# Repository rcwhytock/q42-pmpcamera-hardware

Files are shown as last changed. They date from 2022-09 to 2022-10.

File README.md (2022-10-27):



# Q42 PMP hardware

Q42 PMP is a standalone device featuring a Raspberry Pi and a Raspberry Pi Camera Module with a number of additonal features.

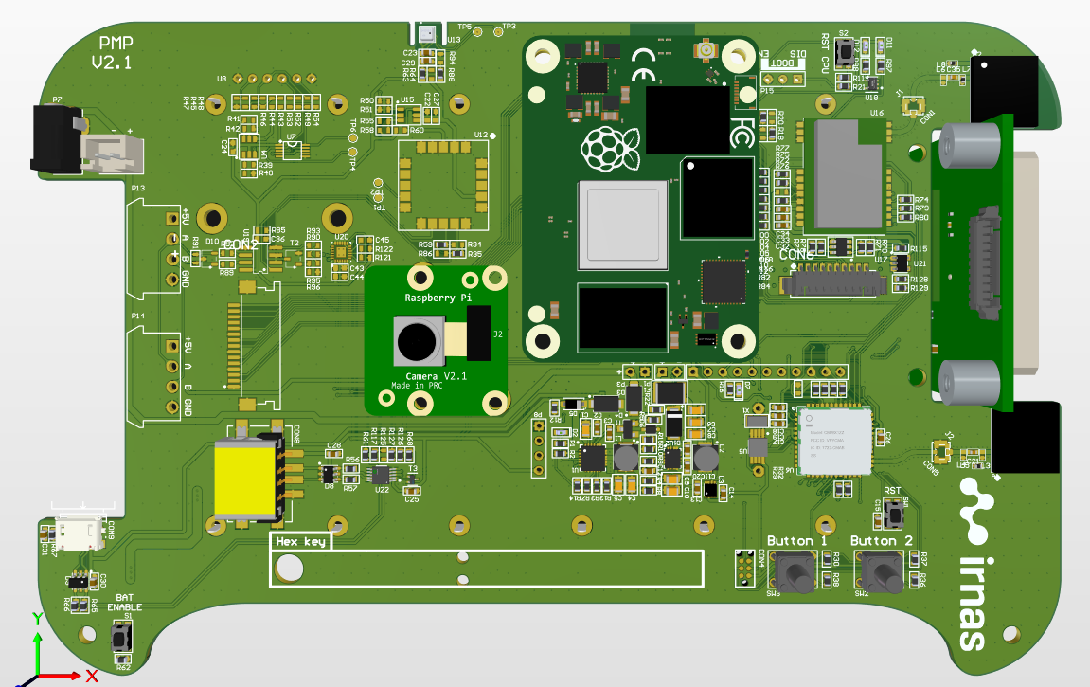
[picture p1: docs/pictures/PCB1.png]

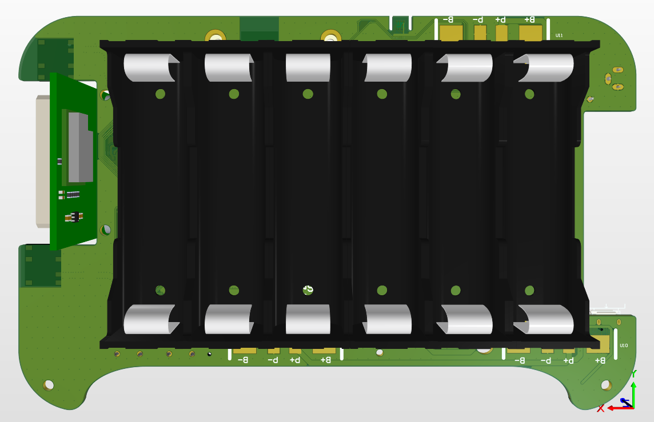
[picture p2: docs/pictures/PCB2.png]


## Key user features
* Capture image/video at defined intervals
* Report system status/sensors via Lora (optional)
* Report system status/sensors via RockBlock Iridium (optional)
* Optional sensors:
  * Ultrasonic distance
  * Temperatures
  * GPS - location
* Power:
  * Batteries
  * Solar charging
* USB flash drive - user removable - contains all images and other captured data
  * contains images/videos
  * contains json with settings
* SD card with OS is read-only and not to be removed
* on/off switch
* 2x push button
  * button 1: test mode - push to turn on the system for 10 minutes
  * button 2: general purpose
* Test mode:
  * WiFi enabled, user can connect and check camera image or download all images
  * Each time test mode is enabled an image is taken.
* Bluetooth:
  * System status printout
  * Enable test mode
  * Configure settings
* Lora:
  * Enable test mode 
  * Configure settings
  * LacunaSpace communication
 
## License

All our projects are as usefully open-source as possible.

Hardware including documentation is licensed under [CERN OHL v.1.2. license](http://www.ohwr.org/licenses/cern-ohl/v1.2)

Firmware and software originating from the project is licensed under [GNU GENERAL PUBLIC LICENSE v3](http://www.gnu.org/licenses/gpl-3.0.en.html).

Open data generated by our projects is licensed under [CC0](https://creativecommons.org/publicdomain/zero/1.0/legalcode).

All our websites and additional documentation are licensed under [Creative Commons Attribution-ShareAlike 4 .0 Unported License](https://creativecommons.org/licenses/by-sa/4.0/legalcode).

What this means is that you can use hardware, firmware, software and documentation without paying a royalty and knowing that you'll be able to use your version forever. You are also free to make changes but if you share these changes then you have to do so on the same conditions that you enjoy.

Koruza, GoodEnoughCNC and IRNAS are all names and marks of Institut IRNAS Race. 
You may use these names and terms only to attribute the appropriate entity as required by the Open Licences referred to above. You may not use them in any other way and in particular you may not use them to imply endorsement or authorization of any hardware that you design, make or sell.

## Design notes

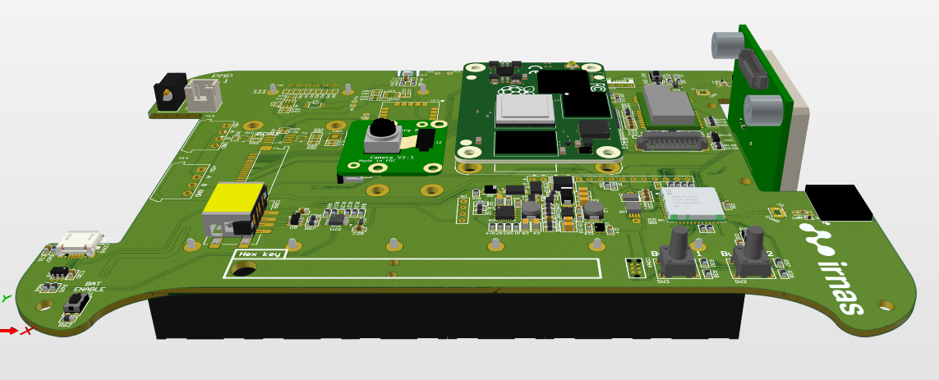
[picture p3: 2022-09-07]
docs/pictures/PCB3.png

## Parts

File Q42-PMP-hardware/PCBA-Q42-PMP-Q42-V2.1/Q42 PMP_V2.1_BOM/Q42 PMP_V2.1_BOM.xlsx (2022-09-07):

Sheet: Part List Report
 | Component list |  |  | Q42 PMP
 | Source Data From: | Q42-PMP.PrjPCB
 | Project: | Q42-PMP.PrjPCB
 | Variant: | Q42
 | Version: | V2.1
 | Report Date: | 7. 09. 2022 | 08:28
 | Print Date: | 2022-09-07 | 8:29:03
# | Manufacturer Part Number | Manufacturer | Description | Footprint | Designator | Value | Quantity | Supplier 1 | Supplier Part Number 1 | #Column Name Error:' IRNAS Internal | Total Quantity
1 |  |  | BATERRY HOLDER 18650 | BATTERY HOLDER 18650 | P5, P6, P9, P10, P11, P12 |  | 6 |  | Battery holder for 18650 |  | 120
2 |  |  | BATTERY PROTECTION | BATTERY PROTECTION | U9, U10, U11 |  | 3 |  | Battery protection |  | 60
3 |  |  | Humidity Temperature Sensor 0 ~ 100% RH I²C, SPI ±3% 1s Surface Mount | BME280 | U13 |  | 1 | Digi-Key | 828-1063-6-ND |  | 20
4 |  |  | Tactile Switch, B3F Series, Top Actuated, Through Hole, Round Button, 100 gf, 50mA at 24VDC | BTN B3F-1070 | SW2, SW3 |  | 2 | Farnell | 959698 |  | 40
5 |  |  | CAP CER 1.5PF 50V C0G/NP0 0402 | CAP0402 | C35 | 1.5pF | 1 | Digi-Key | 490-6212-1-ND |  | 20
6 |  |  | CAP CER 3.0PF 50V C0G/NP0 0402 | CAP0402 | C21 | 3.0pF | 1 | Digi-Key | 490-7756-1-ND |  | 20
7 | C0603C106M8PACTU | KEMET | 10uf/0603/20% | CAP0603 | C19 |  | 1 | Farnell | 2820985 |  | 20
8 | CL10A106KP8NNNC | Samsung | Cap Ceramic 10uF 10V X5R 10% SMD 0603 85C Paper T/R | CAP0603 | C32 |  | 1 | Digi-Key | 1276-1192-1-ND |  | 20
9 | MC0603B473K500CT | MULTICOMP | MULTICOMP - MC0603B473K500CT - CAP, MLCC, X7R, 47NF, 50V, 0603 | CAP0603 | C3 |  | 1 | Farnell | 1759116 |  | 20
10 | GRM188R61C106KAALD | Murata | Multilayer Ceramic Capacitors MLCC - SMD/SMT 0603 10uF 16volts X5R 10% | CAP0603 | C11, C20 |  | 2 | Farnell | 2611923 |  | 40
11 | GRM188R61C475KAAJD | MURATA | MURATA - GRM188R61C475KAAJD - CAP, MLCC, X5R, 4.7UF, 16V, 0603 | CAP0603 | C2 |  | 1 | Farnell | 2611924 |  | 20
12 | GRM188R61C475KAAJD | MURATA | MURATA - GRM188R61C475KAAJD - CAP, MLCC, X5R, 4.7UF, 16V, 0603 | CAP0603 | C13 |  | 1 | Farnell | 2611924 |  | 20
13 | GRM188R61H105KAALD | MURATA | MURATA - GRM188R61H105KAALD - CAP, MLCC, X5R, 1UF, 50V, 0603 | CAP0603 | C17 |  | 1 | Farnell | 1845736 |  | 20
14 | GRM188R61H105KAALD | MURATA | MURATA - GRM188R61H105KAALD - CAP, MLCC, X5R, 1UF, 50V, 0603 | CAP0603 | C26, C29, C33 |  | 3 | Farnell | 1845736 |  | 60
15 | GRM188R71C104KA01J | MURATA | MURATA - GRM188R71C104KA01J - CAP, MLCC, X7R, 0.1UF, 16V, 0603 | CAP0603 | C12, C15, C18, C25 |  | 4 | Farnell | 2688519 |  | 80
16 | GRM188R71C104KA01J | MURATA | MURATA - GRM188R71C104KA01J - CAP, MLCC, X7R, 0.1UF, 16V, 0603 | CAP0603 | C23, C28, C30, C31, C34 |  | 5 | Farnell | 2688519 |  | 100
17 |  |  | SMD Multilayer Ceramic Capacitor, 2.2 µF, 6.3 V, 0603 [1608 Metric], ± 10%, X5R, MC Series | CAP0603 | C14 |  | 1 | Farnell | 1759392 |  | 20
18 | MC0805X226M6R3CT | MULTICOMP | MULTICOMP - MC0805X226M6R3CT - CAP, MLCC, X5R, 22UF, 0805 | CAP0805 | C7, C8, C9, C10 |  | 4 | Farnell | 1759415 |  | 80
19 | CGA4J1X5R1C106K125AC | TDK | TDK - CGA4J1X5R1C106K125AC - CAP, MLCC, X5R, 10UF, 16V, 0805 | CAP0805 | C1, C4, C5, C6 |  | 4 | Farnell | 2320856 |  | 80
20 | MINISMDC150F/24-2 | LITTELFUSE | LITTELFUSE - MINISMDC150F/24-2 - POLYSWITCH, SMD, 1812, 1.5A | Chip2PinSM127P600-8N | F1 |  | 1 | Farnell | 1345929 |  | 20
21 | MM8130-2600 | Murata | Coaxial Connector with Switch | COAXIAL-SWF | J1, J2 | MM8130-2600 | 2 |  |  |  | 40
22 |  |  |  | E22-900M22S | U16 |  | 1 |  |  |  | 20
23 | FDSD0420-H-1R5M=P3 | MURATA | MURATA - FDSD0420-H-1R5M=P3 - INDUCTOR, SHIELDED, 1.5UH, 5.1A, 20% | FDSD0402 | L1, L2 |  | 2 | Farnell | 2530091 |  | 40
24 |  |  | Header, 3-Pin | HDR1X3 | P15 |  | 1 |  |  |  | 20
25 | LQG15WH18NJ02D | MURATA | 18 nH, 0.8 ohm, 2.3 GHz, 260 mA, 0402 | IND0402 | L7 | 18nH | 1 | Farnell | 3263541 |  | 20
26 |  |  | IND 12NH 500MA 280 MOHM | IND0402 | L3 | 12nH | 1 | Digi-Key | 490-2624-1-ND |  | 20
27 |  |  | Multilayer Inductor, 1 nH, 0.07 ohm, 10 GHz, 1 A, 0402 [1005 Metric], LQG15HS_02 Series | IND0402 | L8 |  | 1 | Farnell | 3471230 |  | 20
28 |  |  | Multilayer Inductor, AEC-Q200, 2.1 nH, 0.06 ohm, 8 GHz, 1 A, 0402 [1005 Metric], LQG15WH_02 Series | IND0402 | L5 |  | 1 | Farnell | 3263552 |  | 20
29 |  |  | Wire-To-Board Connector, Vertical, 2.5 mm, 2 Contacts, Header, XH Series, Through Hole, 1 Rows | JST_2PIN_TH | CON7 |  | 1 | Farnell | 1516276 |  | 20
30 | HSMS-C190 | BROADCOM LIMITED | BROADCOM LIMITED - HSMS-C190 - LED, RED, 10MCD, 626NM | LED0603 | D12 |  | 1 | Farnell | 2497356 |  | 20
31 | HSMS-C190 | BROADCOM LIMITED | BROADCOM LIMITED - HSMS-C190 - LED, RED, 10MCD, 626NM | LED0603 | D2 |  | 1 | Farnell | 2497356 |  | 20
32 | HSMS-C190 | BROADCOM LIMITED | HSME-C191 - LED, Green, SMD, 0603, 20 mA, 2.1 V, 572 nm | LED0603 | D7, D11 |  | 2 | Farnell | 1219743 |  | 40
33 | LFXTAL009678 | IQD | CRYSTAL, 32.768KHZ, 12.5PF, SMD | LFXTAL009678 | X1 |  | 1 | Farnell | 2449398 |  | 20
34 | CMWX1ZZABZ-091 | Murata | Lora Module Murata | Lora Module ES0 | U6 |  | 1 | Farnell | 2802546 |  | 20
35 | SR42I010-R | Antenova | Antenna SMD -4dBi Gain 870MHz/928MHz Automotive 7-Pin SMD T/R | LORA_PCB_ANTENNA | A2 |  | 1 | Mouser | 237-SR42I010-L |  | 20
36 |  |  |  | microUSB-CHINA | CON9 |  | 1 |  |  |  | 20
37 |  |  | Analogue Switch, UART, 2 Channels, DPDT, 4.5 ohm, 2.4V to 3.6V, MSOP, 10 Pins | MSOP-10 | U22 |  | 1 | Farnell | 2564479 |  | 20
38 |  |  | Wire-To-Board Connector, Right Angle, 1.25 mm, 10 Contacts, Header, PicoBlade 53261 Series | PICOBLADE 10PIN | CON6 |  | 1 | Farnell | 1125377 |  | 20
39 | BQ24296RGET | Texas Instruments | IC LI+ CHARGER PWR MGMT 24VQFN | QFN4x4 | U1 |  | 1 | Farnell | 2373541 |  | 20
40 |  |  | Raspberry Pi Compute Module 4 (! order 2 connectors !) | Raspberry pi CM4 | CM4 |  | 1 | Farnell | 3493346 |  | 20
41 | CR0603-J/-000ELF | BOURNS | BOURNS - CR0603-J/-000ELF - RES, THICK FILM, 0R, 5%, 0.1W, 0603 | RES0603 | R4, R22 |  | 2 | Farnell | 2008343 |  | 40
42 | CR0603-J/-000ELF | BOURNS | BOURNS - CR0603-J/-000ELF - RES, THICK FILM, 0R, 5%, 0.1W, 0603 | RES0603 | R18, R19, R21, R35, R59, R63, R69, R75, R76, R79, R80, R81, R84, R88, R115, R116, R117, R120 |  | 18 | Farnell | 2008343 |  | 360
43 | MC0063W060311M | MULTICOMP | MULTICOMP - MC0063W060311M - RES, THICK FILM, 1M, 1%, 0.063W, 0603 | RES0603 | R67 |  | 1 | Farnell | 9330410 |  | 20
44 | MC0063W06031100R | MULTICOMP | MULTICOMP - MC0063W06031100R - RES, THICK FILM, 100R, 1%, 0.063W, 0603 | RES0603 | R25, R28, R62, R70, R78, R100, R102, R103, R104, R105, R106, R107, R108, R109, R110, R111, R112, R128 |  | 18 | Farnell | 9330364 |  | 360
45 | MCMR06X102 JTL | MULTICOMP | MULTICOMP - MCMR06X102 JTL - RES, CERAMIC, 1K, 5%, 0.1W, 0603 | RES0603 | R16, R38, R97, R98 |  | 4 | Farnell | 2073354 |  | 80
46 | MCMR06X103 JTL | MULTICOMP | MULTICOMP - MCMR06X103 JTL - RES, CERAMIC, 10K, 5%, 0.1W, 0603 | RES0603 | R9, R10, R15 |  | 3 | Farnell | 2073356 |  | 60
47 | MCMR06X103 JTL | MULTICOMP | MULTICOMP - MCMR06X103 JTL - RES, CERAMIC, 10K, 5%, 0.1W, 0603 | RES0603 | R30, R37, R74, R77, R127, R129 |  | 6 | Farnell | 2073356 |  | 120
48 | MCMR06X104 JTL | MULTICOMP | MULTICOMP - MCMR06X104 JTL - RES, CERAMIC, 100K, 5%, 0.1W, 0603 | RES0603 | R32 |  | 1 | Farnell | 2073357 |  | 20
49 | MCMR06X104 JTL | MULTICOMP | MULTICOMP - MCMR06X104 JTL - RES, CERAMIC, 100K, 5%, 0.1W, 0603 | RES0603 | R71, R73 |  | 2 | Farnell | 2073357 |  | 40
50 | MCMR06X471 JTL | MULTICOMP | MULTICOMP - MCMR06X471 JTL - RES, CERAMIC, 470R, 5%, 0.1W, 0603 | RES0603 | R1, R14 |  | 2 | Farnell | 2073513 |  | 40
51 | MCMR06X2201FTL | MULTICOMP | MULTICOMP - MCMR06X2201FTL - RES, CERAMIC, 2K2, 1%, 0.1W, 0603 | RES0603 | R36 |  | 1 | Farnell | 2073429 |  | 20
52 | MCMR06X4701FTL | MULTICOMP | MULTICOMP - MCMR06X4701FTL - RES, CERAMIC, 4K7, 1%, 0.1W, 0603 | RES0603 | R6, R11 |  | 2 | Farnell | 2073509 |  | 40
53 | MCMR06X4702FTL | MULTICOMP | MULTICOMP - MCMR06X4702FTL - RES, CERAMIC, 47K, 1%, 0.1W, 0603 | RES0603 | R61, R68 |  | 2 | Farnell | 2073510 |  | 40
54 | MCMR06X5601FTL | MULTICOMP | MULTICOMP - MCMR06X5601FTL - RES, CERAMIC, 5K6, 1%, 0.1W, 0603 | RES0603 | R3 |  | 1 | Farnell | 2073537 |  | 20
55 | MCWR06X1503FTL | MULTICOMP | MULTICOMP - MCWR06X1503FTL - RES, THICK FILM, 150KOHM, 1%, 0.1W | RES0603 | R8 |  | 1 | Farnell | 2447254 |  | 20
56 | MCWR06X2200FTL | MULTICOMP | MULTICOMP - MCWR06X2200FTL - RES, THICK FILM, 220R, 1%, 0.1W, 0603 | RES0603 | R7 |  | 1 | Farnell | 2447298 |  | 20
57 | MCWR06X2200FTL | MULTICOMP | MULTICOMP - MCWR06X2200FTL - RES, THICK FILM, 220R, 1%, 0.1W, 0603 | RES0603 | R114 |  | 1 | Farnell | 2447298 |  | 20
58 | MCWR06X3302FTL | MULTICOMP | MULTICOMP - MCWR06X3302FTL - RES, THICK FILM, 33K, 1%, 0.1W, 0603 | RES0603 | R13 |  | 1 | Farnell | 2447342 |  | 20
59 | MCWR06X3901FTL | MULTICOMP | MULTICOMP - MCWR06X3901FTL - RES, THICK FILM, 3K9, 1%, 0.1W, 0603 | RES0603 | R5 |  | 1 | Farnell | 2447363 |  | 20
60 |  |  | SMD Chip Resistor, 5.1 kohm, ± 1%, 100 mW, 0603 [1608 Metric], Thick Film, General Purpose | RES0603 | R126 |  | 1 | Farnell | 1469819 |  | 20
61 |  |  | Thermistor, NTC, 10 kohm, B57321V2 Series, 4000 K, SMD, 0603 [1608 Metric] | RES0603 | R2 |  | 1 | Farnell | 1299914 |  | 20
62 | CRCW0603226KFKEA | Vishay | Thick Film Resistors - SMD 1/10watt 226Kohms 1% | RES0603 | R29 |  | 1 | Farnell | 2138531 |  | 20
63 | RCA060310R0FKEA | VISHAY | VISHAY - RCA060310R0FKEA - RES, AUTO, THICK FILM, 10R, 1%, 0603 | RES0603 | R12 |  | 1 | Farnell | 2616585 |  | 20
64 | RCA060310R0FKEA | VISHAY | VISHAY - RCA060310R0FKEA - RES, AUTO, THICK FILM, 10R, 1%, 0603 | RES0603 | R56, R57, R65, R66 |  | 4 | Farnell | 2616585 |  | 80
65 | RS1J-E3/61T.. | VISHAY | VISHAY - RS1J-E3/61T.. - DIODE, FAST, 1A, 600V, SMD | SMC/DO-214AC | D1 |  | 1 | Farnell | 9550143 |  | 20
66 | BZT52C6V2 | DIODES INC. | DIODES INC. - BZT52C6V2 - DIODE, ZENER, 6.2V, 0.5W, SOD-123 | SOD123 | D5 |  | 1 | Farnell | 1902438 |  | 20
67 | MM3Z3V0T1G | ON SEMICONDUCTOR | ON SEMICONDUCTOR - MM3Z3V0T1G - ZENER DIODE, 200MW, 3V, SOD-323 | SOD-323 2L | D6 |  | 1 | Farnell | 2463510 |  | 20
68 | SE30AFG-M3/6A | VISHAY | VISHAY - SE30AFG-M3/6A - RECTIFIER, ESD, 400V, 3A, DO-221AC | SODFL127P600-8N | D3, D4 |  | 2 | Farnell | 2313878 |  | 40
69 |  |  | ESD Protection Device, 17 V, SOT-23, 6 Pins, 6 V, 85 W, USBLC Series | SOT23-6 | D8, D9 |  | 2 | Farnell | 1269406 |  | 40
70 | MMBT3904 | ON SEMICONDUCTOR/FAIRCHILD | ON SEMICONDUCTOR/FAIRCHILD - MMBT3904 - TRANSISTOR, NPN, SOT-23 | SOT23127P600-8N | T1 |  | 1 | Farnell | 9846727 |  | 20
71 |  |  | 1.0 A Load Switch IC | SOT-25 | U21 | TCK106AF | 1 | Digi-Key | TCK106AFLFCT-ND |  | 20
72 |  |  | Buffer, 74LVC1G07, 1.65 V to 5.5 V, SOT-353-5 | SOT-353 | U18 |  | 1 | Farnell | 1845213 |  | 20
73 |  |  | Power MOSFET, N Channel, 20 V, 630 mA, 0.3 ohm, SOT-523, Surface Mount | SOT-523 | T3 |  | 1 | Farnell | 2543524 |  | 20
74 | SR42I010-R | Antenova | Antenna SMD -4dBi Gain 870MHz/928MHz Automotive 7-Pin SMD T/R | SR42I010-L | A1 |  | 1 | Mouser | 237-SR42I010-R |  | 20
75 | KMR221NGLFS | ITT C&K | SWITCH TACTILE SPST-NO 0.05A 32V | SW | S1, S2 |  | 2 | Farnell | 2845727 |  | 40
76 | KMR221NGLFS | ITT C&K | SWITCH TACTILE SPST-NO 0.05A 32V | Tactile button | SW1 |  | 1 | C&K Components | 2845727 |  | 20
77 |  |  | TEST POINT ROUND SMD | TestPoint:1.2x1.2mm | TP1, TP2, TP3, TP4, TP5, TP6 |  | 6 |  |  |  | 120
78 | ISL1208IU8Z-T7A | Intersil | IC RTC/CALENDAR I2C LP 8MSOP | TSOP65P500X110-8N | U5 |  | 1 | Farnell | 2543322 |  | 20
79 |  |  | Dual MOSFET, N and P Channel, 3.4 A, 30 V, 0.038 ohm, 10 V, 1 V | TSOT26 | U17 |  | 1 | Farnell | 2061522 |  | 20
80 |  |  | LDO Voltage Regulator, Fixed, 2.5 V to 5.5 V in, 3.3 V/150 mA out, 380 mV drop, VDFN-8 | VDFN_2x2 | U3 |  | 1 | Farnell | 2678434 |  | 20
81 | TPS630701RNMT | TEXAS INSTRUMENTS | TEXAS INSTRUMENTS - TPS630701RNMT - DC/DC CONV, BUCK-BOOST, 2.4MHZ, VQFN-15 | VQFN TPS | U2 |  | 1 | Farnell | 2643432 |  | 20
82 |  |  | USB Connector, USB Type A, USB 2.0, Receptacle, 4 Ways, Surface Mount, Horizontal | WE-629104190121 | CON8 |  | 1 | Farnell | 2749036 |  | 20
 |  |  |  |  |  | 0 | 169
Approved |  |  |  | Notes
 |  |  |  | pcs: |  |  | 20 |  | Total |  | #REF!
 |  |  |  |  |  |  |  |  | Price for 1pcs |  | #REF!

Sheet: Project Information
Project Full Path | C:\Users\HP\AppData\Local\TempReleases\Snapshot\1\Q42-PMP.PrjPCB
Project Filename | Q42-PMP.PrjPCB
Variant Name | Q42
Data-Source Filename | Q42-PMP.PrjPCB
Data-Source Full Path | C:\Users\HP\AppData\Local\TempReleases\Snapshot\1\Q42-PMP.PrjPCB
Title | BOM for Variant [Q42] of Project [Q42-PMP.PrjPCB] (No PCB Document Selected)
Total Quantity | 169
Report Time | 08:28
Report Date | 7. 09. 2022
Report Date & Tine | 7. 09. 2022 08:28
Output Name | BOM
Output Type | BomReport
Output Generator Name | BOM
Output Generator Description | Bill of Materials

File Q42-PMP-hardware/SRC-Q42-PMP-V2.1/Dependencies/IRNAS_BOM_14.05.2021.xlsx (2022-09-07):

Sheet: Part List Report
 | Component list |  |  | Field=ProjectTitle
 | Source Data From: | Field=DataSourceFileName
 | Project: | Field=ProjectFileName
 | Variant: | Field=VariantName
 | Version: | Field=Version
 | Report Date: | Field=ReportDate | Field=ReportTime
 | Print Date: | 2021-07-15 | 9:00:45
# | Column=Manufacturer Part Number | Column=Manufacturer | Column=Description | Column=Footprint | Column=Designator | Column=Value | Column=Quantity | Column=Supplier 1 | Column=Supplier Part Number 1 | Column=IRNAS Internal | Total Quantity
1 |  |  |  |  |  |  |  |  |  |  | #VALUE!
2 |  |  |  |  |  |  |  |  |  |  | #VALUE!
3 |  |  |  |  |  |  |  |  |  |  | #VALUE!
 |  |  |  |  |  | 0 | 0
Approved |  |  |  | Notes
 |  |  |  | pcs: |  |  | Field=ProductionQuantity |  | Total |  | #REF!
 |  |  |  |  |  |  |  |  | Price for 1pcs |  | #REF!

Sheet: Project Information
Project Full Path | Field=ProjectFullPath
Project Filename | Field=ProjectFileName
Variant Name | Field=VariantName
Data-Source Filename | Field=DataSourceFileName
Data-Source Full Path | Field=DataSourceFullPath
Title | Field=Title
Total Quantity | Field=TotalQuantity
Report Time | Field=ReportTime
Report Date | Field=ReportDate
Report Date & Tine | Field=ReportDateTime
Output Name | Field=OutputName
Output Type | Field=OutputType
Output Generator Name | Field=GeneratorName
Output Generator Description | Field=GeneratorDescription

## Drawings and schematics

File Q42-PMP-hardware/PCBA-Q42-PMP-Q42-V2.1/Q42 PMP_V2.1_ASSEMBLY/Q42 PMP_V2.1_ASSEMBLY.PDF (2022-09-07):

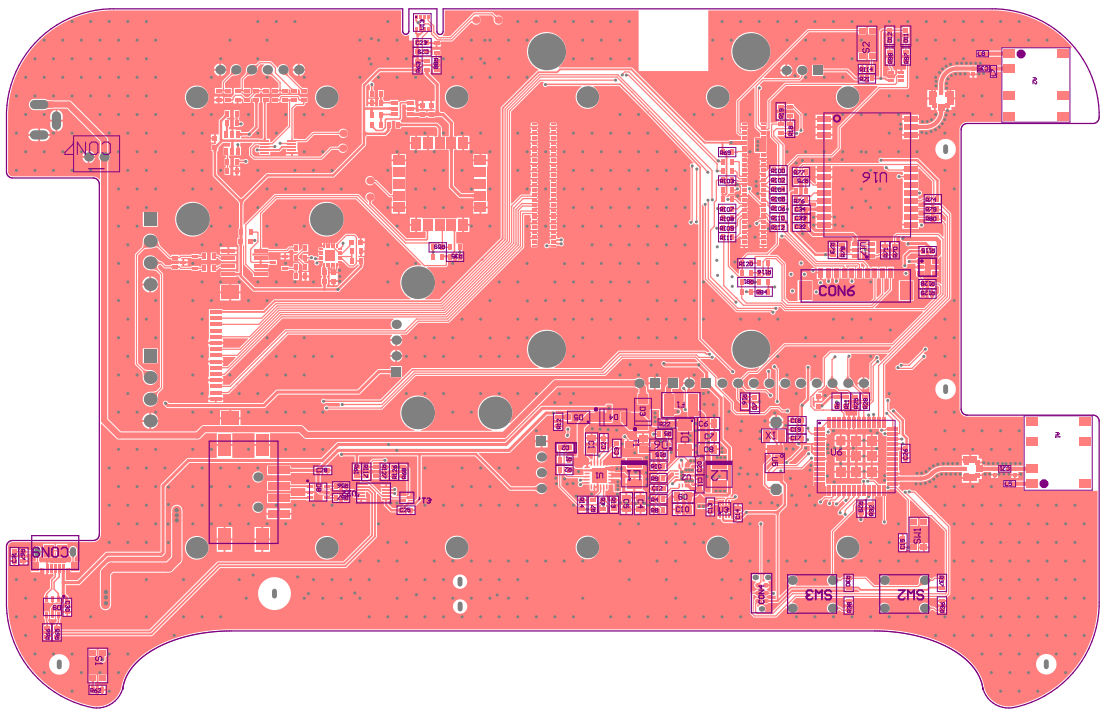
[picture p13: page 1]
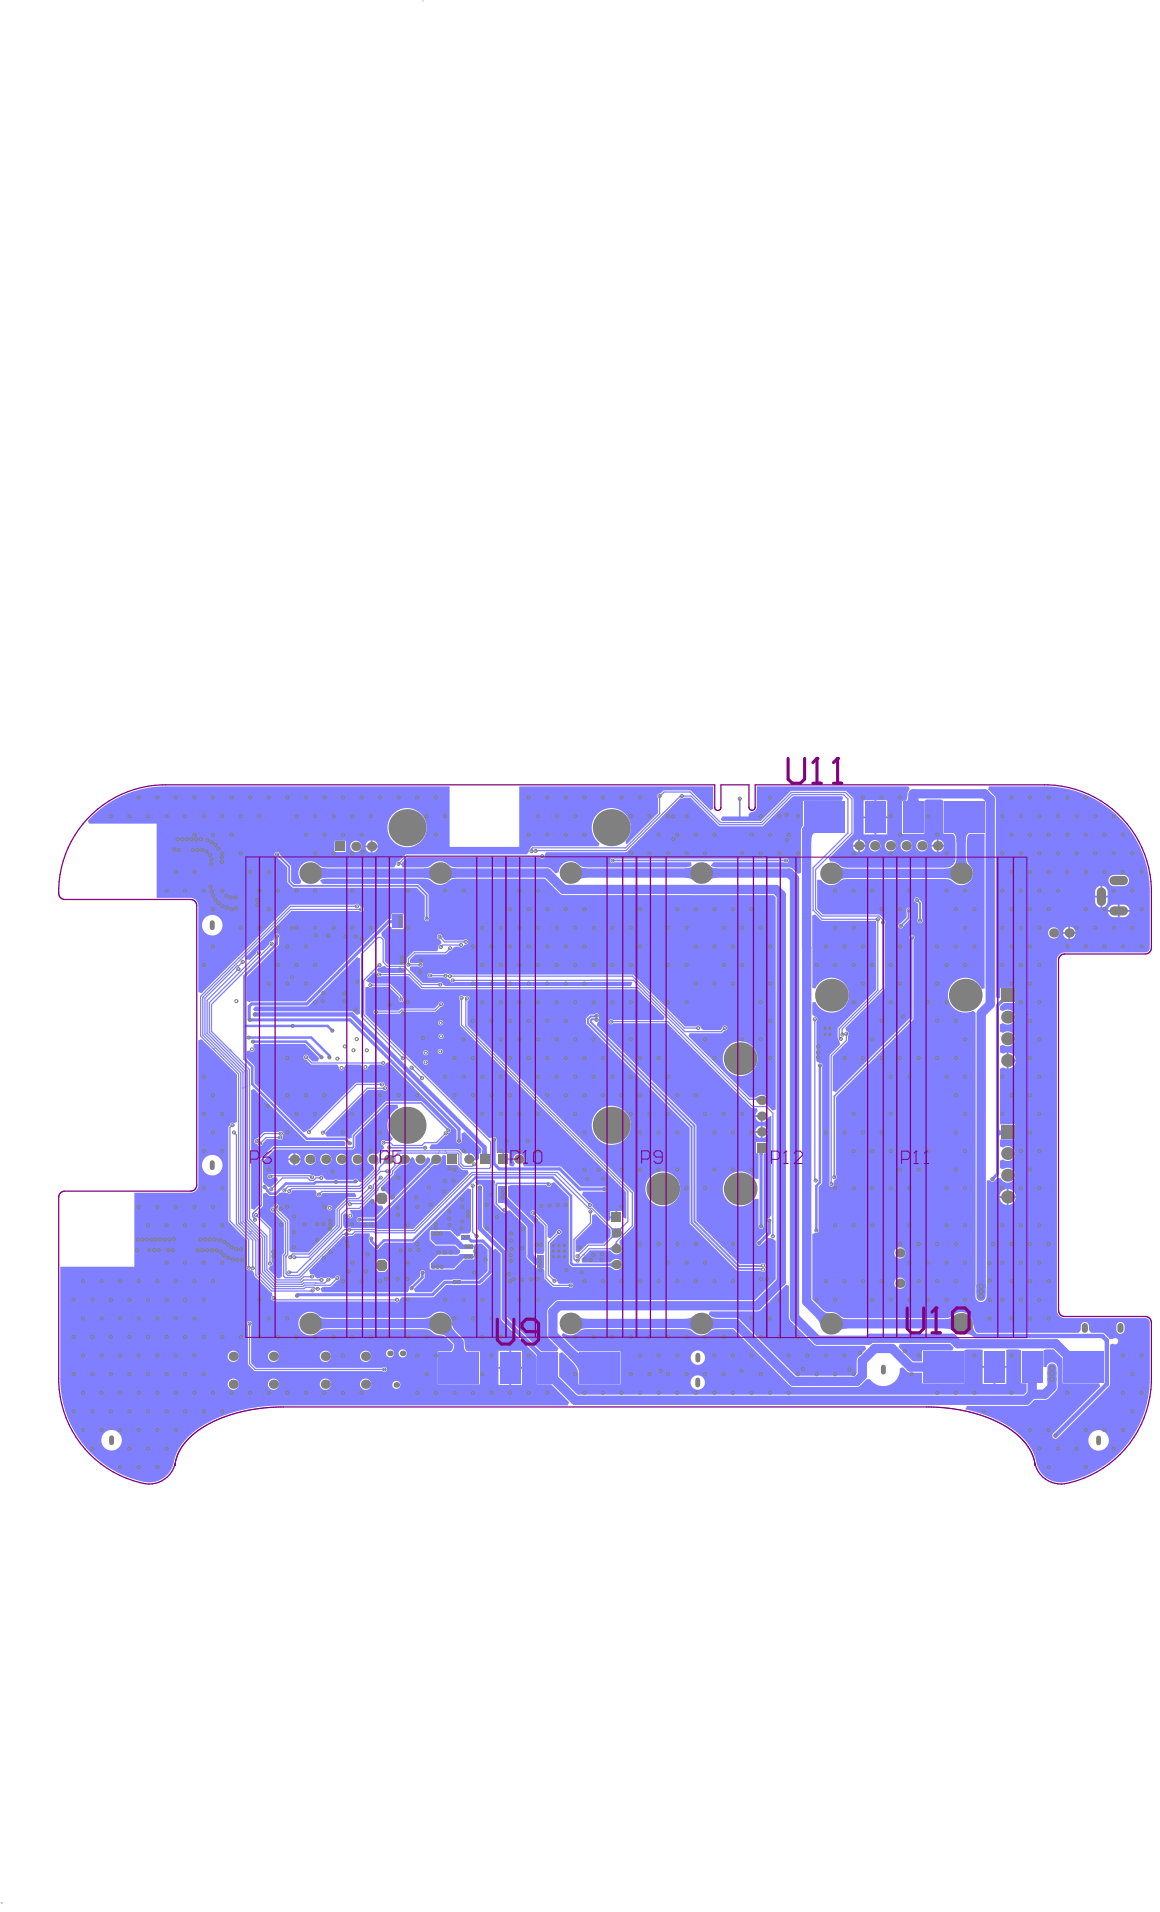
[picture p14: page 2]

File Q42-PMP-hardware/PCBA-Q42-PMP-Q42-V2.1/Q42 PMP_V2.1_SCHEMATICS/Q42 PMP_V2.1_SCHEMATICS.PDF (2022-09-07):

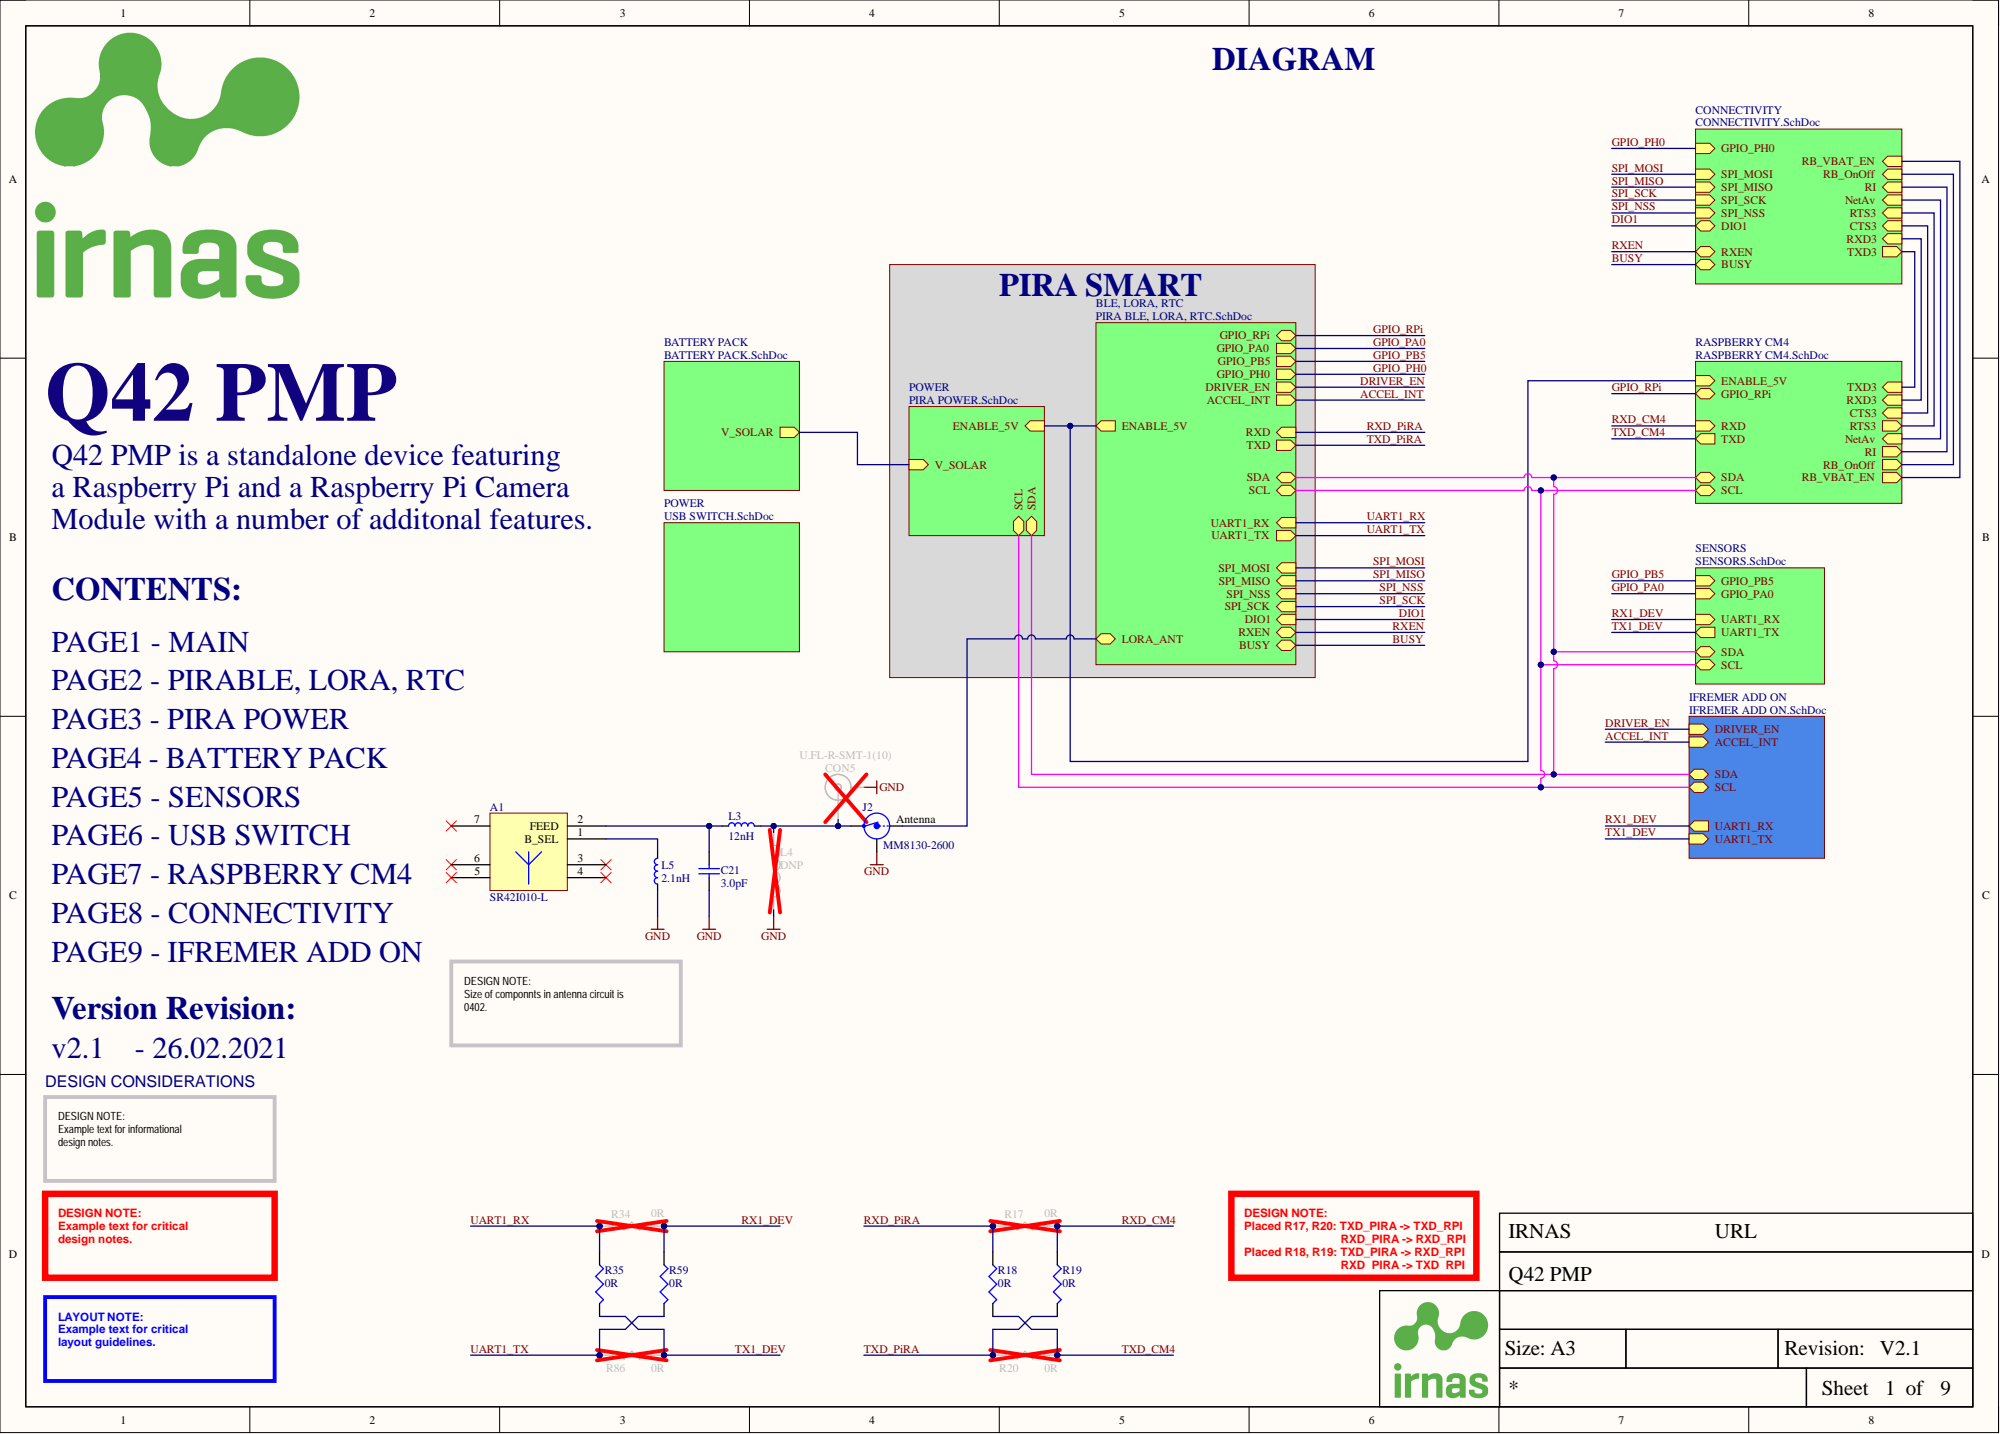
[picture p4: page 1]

BLE, LORA, RTC
PIRA BLE, LORA, RTC.SchDoc

DRIVER_EN ACCEL_INT ENABLE_5V RXD TXD SDA SCL UART1_RX | GPIO_RPi ACCEL_INT RXD_CM4 RXD_PiRA TXD_CM4 TXD_PiRA

Q42 PMP is a standalone device featuring
a Raspberry Pi and a Raspberry Pi Camera
Module with a number of additonal features.

UART1_TX SPI_MOSI SPI_MISO SPI_NSS SPI_SCK DIO1 RXEN LORA_ANT BUSY

DESIGN NOTE:
Size of componnts in antenna circuit is

Example text for informational
design notes.

Example text for critical

LAYOUT NOTE:
layout guidelines.

Size: A3 | | Revision: V2.1

Sheet of

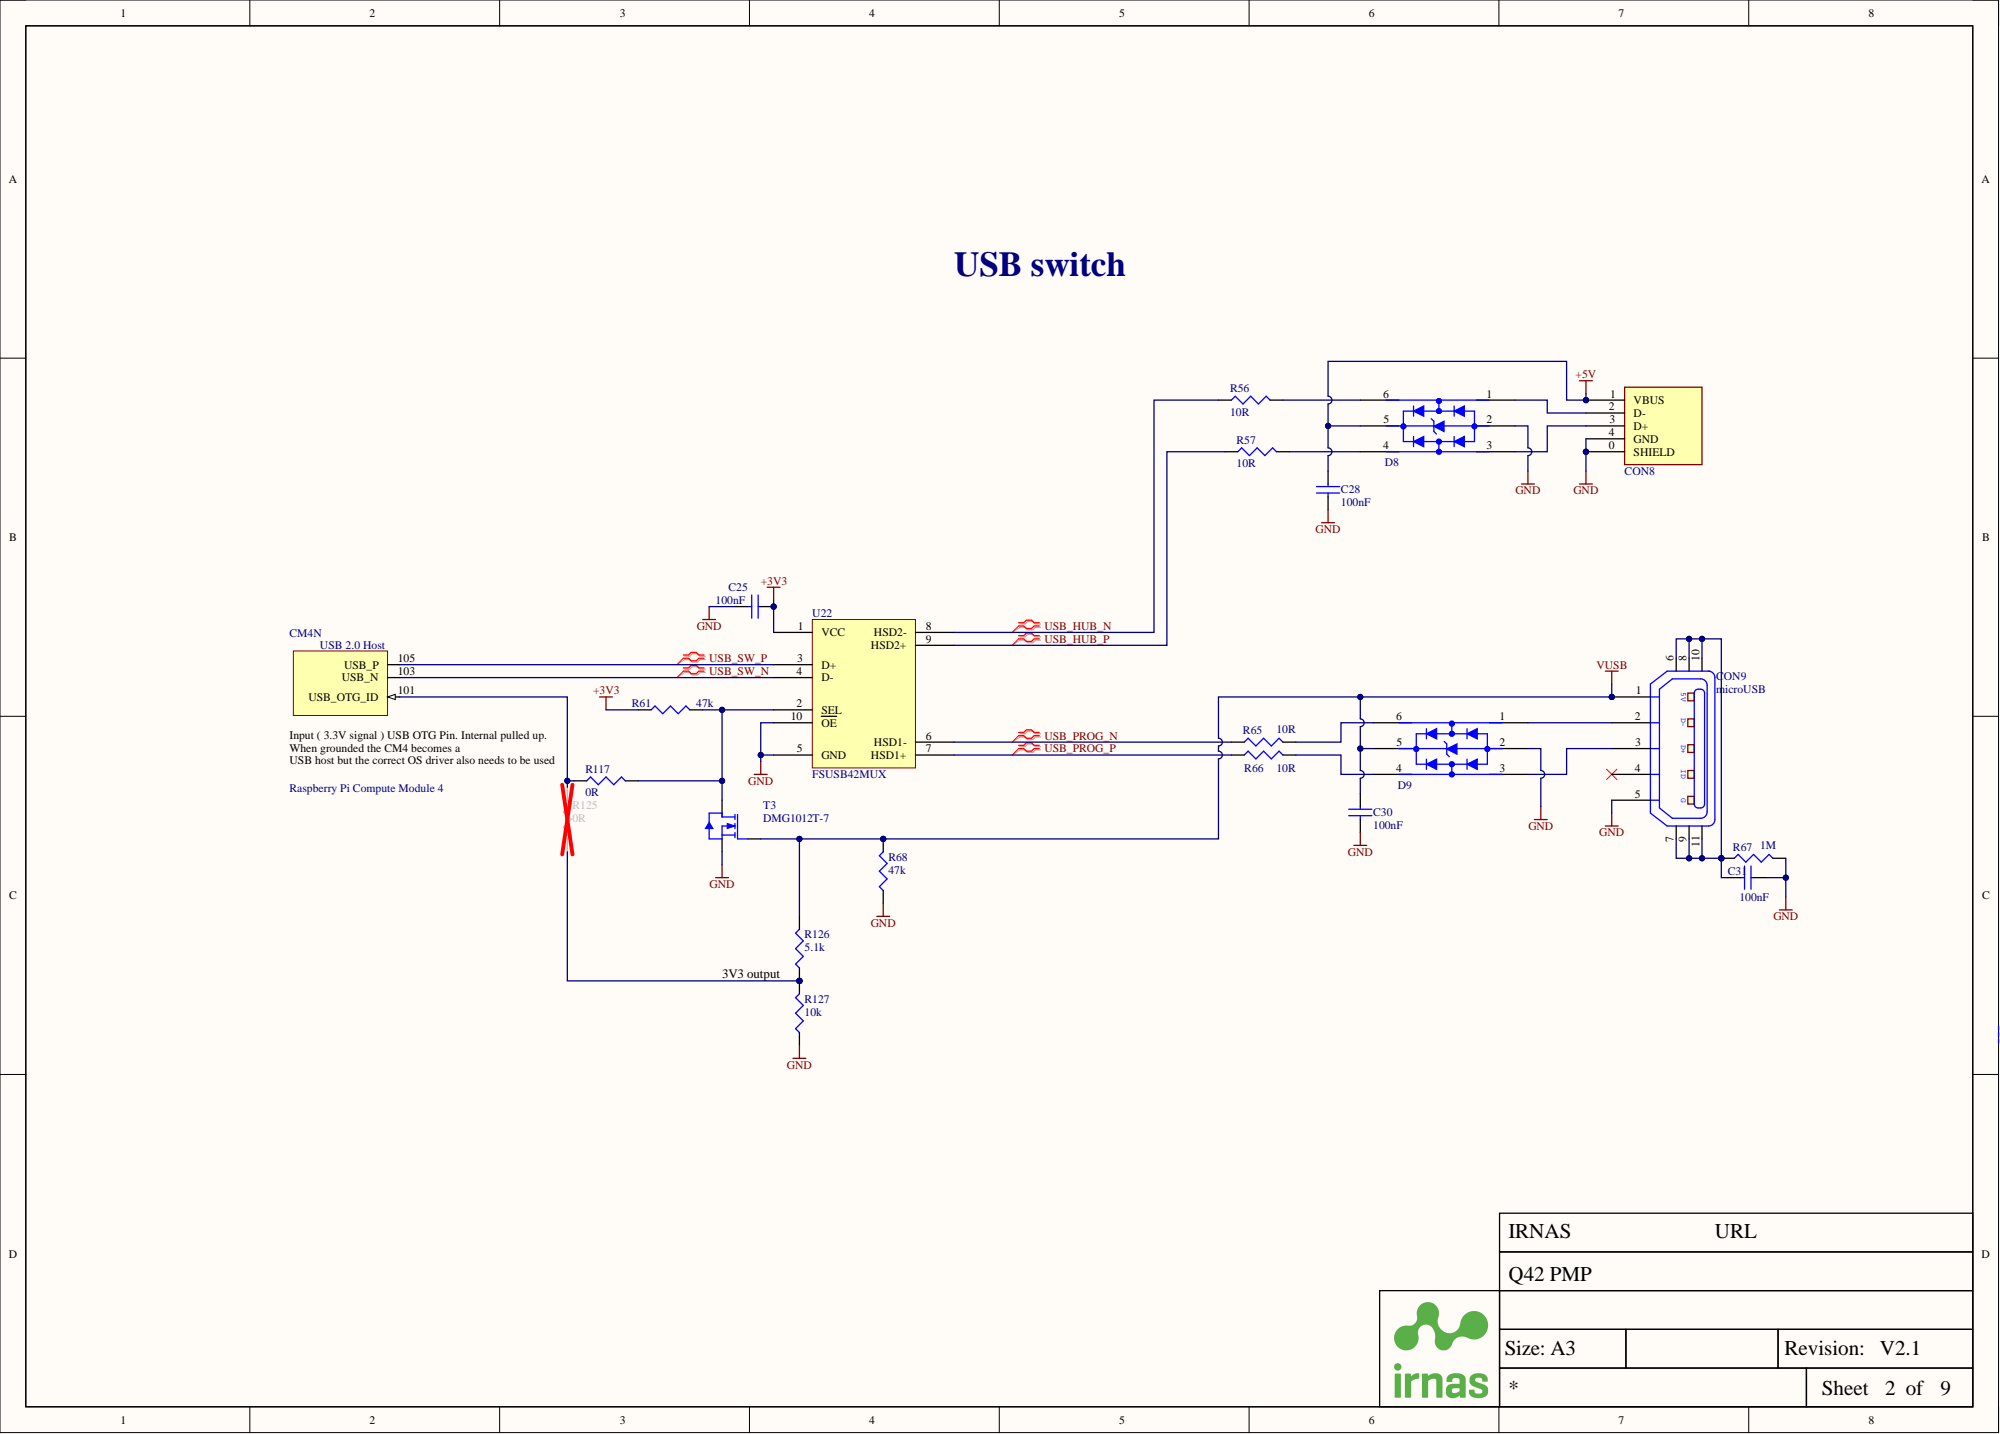
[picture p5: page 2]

Input ( 3.3V signal ) USB OTG Pin. Internal pulled up.
When grounded the CM4 becomes a
USB host but the correct OS driver also needs to be used

Raspberry Pi Compute Module 4

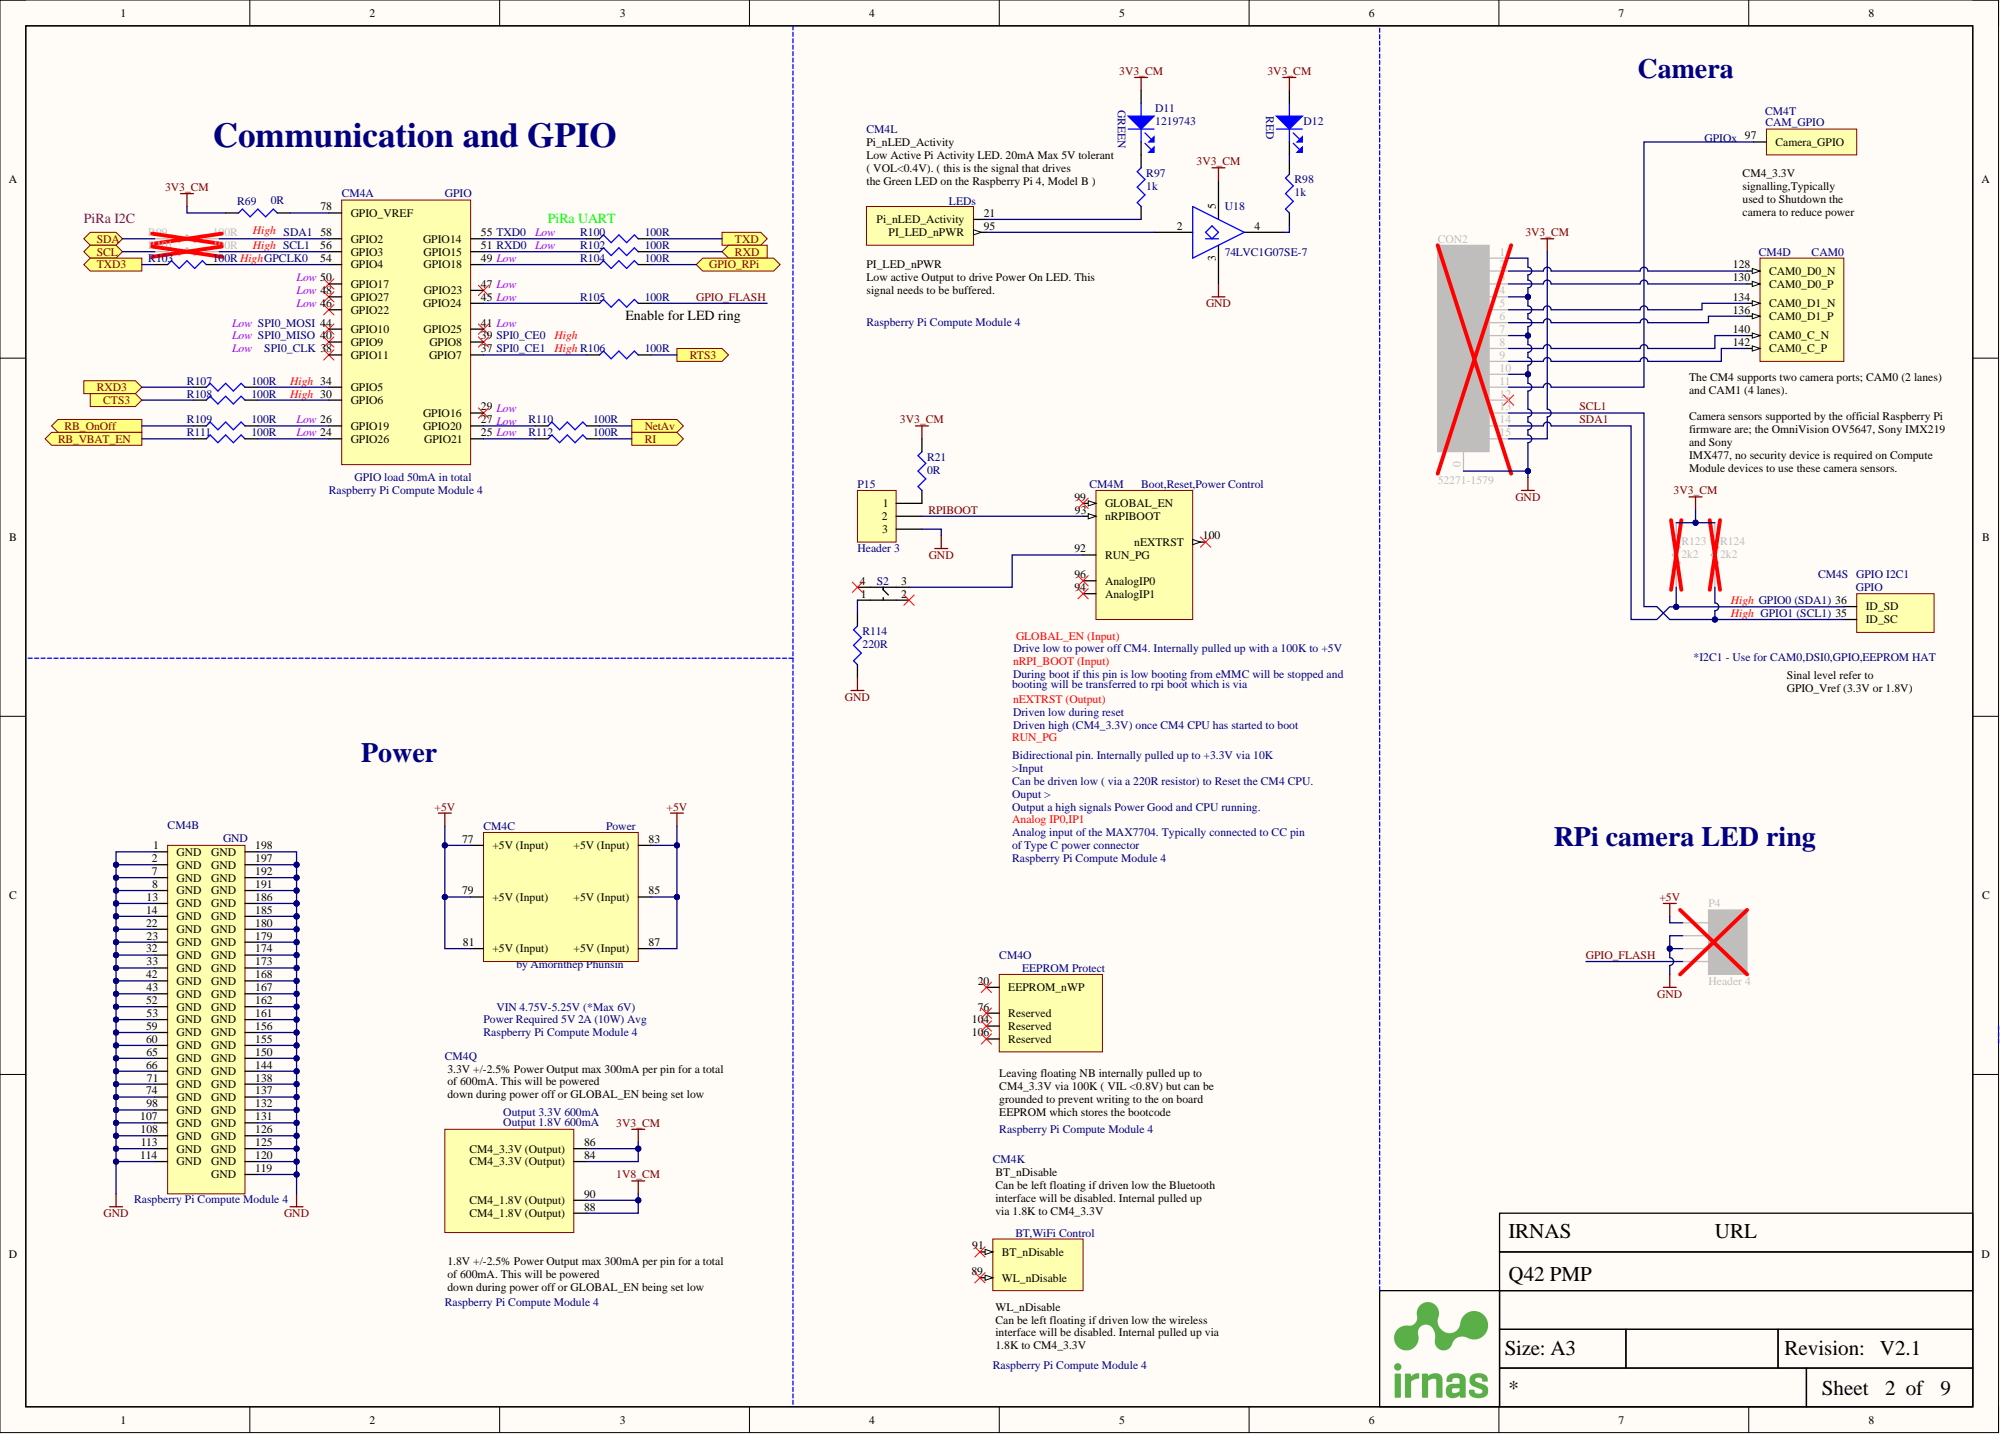
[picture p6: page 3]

Pi_nLED_Activity
Low Active Pi Activity LED. 20mA Max 5V tolerant
( VOL<0.4V). ( this is the signal that drives
the Green LED on the Raspberry Pi 4, Model B )

signalling,Typically
used to Shutdown the
camera to reduce power

PI_LED_nPWR
Low active Output to drive Power On LED. This
signal needs to be buffered.

3 | CAM0_D0_P 130
4 | | CAM0_D1_N 134

Enable for LED ring

Raspberry Pi Compute Module 4

The CM4 supports two camera ports; CAM0 (2 lanes)
and CAM1 (4 lanes).

Camera sensors supported by the official Raspberry Pi
firmware are; the OmniVision OV5647, Sony IMX219
and Sony
IMX477, no security device is required on Compute
Module devices to use these camera sensors.

GPIO load 50mA in total

Boot,Reset,Power Control

GLOBAL_EN (Input)
Drive low to power off CM4. Internally pulled up with a 100K to +5V
nRPI_BOOT (Input)
During boot if this pin is low booting from eMMC will be stopped and
booting will be transferred to rpi boot which is via
nEXTRST (Output)
Driven low during reset
Driven high (CM4_3.3V) once CM4 CPU has started to boot
RUN_PG
Bidirectional pin. Internally pulled up to +3.3V via 10K
>Input
Can be driven low ( via a 220R resistor) to Reset the CM4 CPU.
Ouput >
Output a high signals Power Good and CPU running.
Analog IP0,IP1
Analog input of the MAX7704. Typically connected to CC pin
of Type C power connector

*I2C1 - Use for CAM0,DSI0,GPIO,EEPROM HAT

Sinal level refer to
GPIO_Vref (3.3V or 1.8V)

RPi camera LED ring

GND 2

GND 8

GND 22
GND 23
GND 32
GND 33
GND 42
GND 43

GND 53

VIN 4.75V-5.25V (*Max 6V)
Power Required 5V 2A (10W) Avg

3.3V +/-2.5% Power Output max 300mA per pin for a total
of 600mA. This will be powered
down during power off or GLOBAL_EN being set low

GND 66

Leaving floating NB internally pulled up to
CM4_3.3V via 100K ( VIL <0.8V) but can be
grounded to prevent writing to the on board
EEPROM which stores the bootcode

GND 74

BT_nDisable
Can be left floating if driven low the Bluetooth
interface will be disabled. Internal pulled up
via 1.8K to CM4_3.3V

1.8V +/-2.5% Power Output max 300mA per pin for a total

WL_nDisable
Can be left floating if driven low the wireless
interface will be disabled. Internal pulled up via

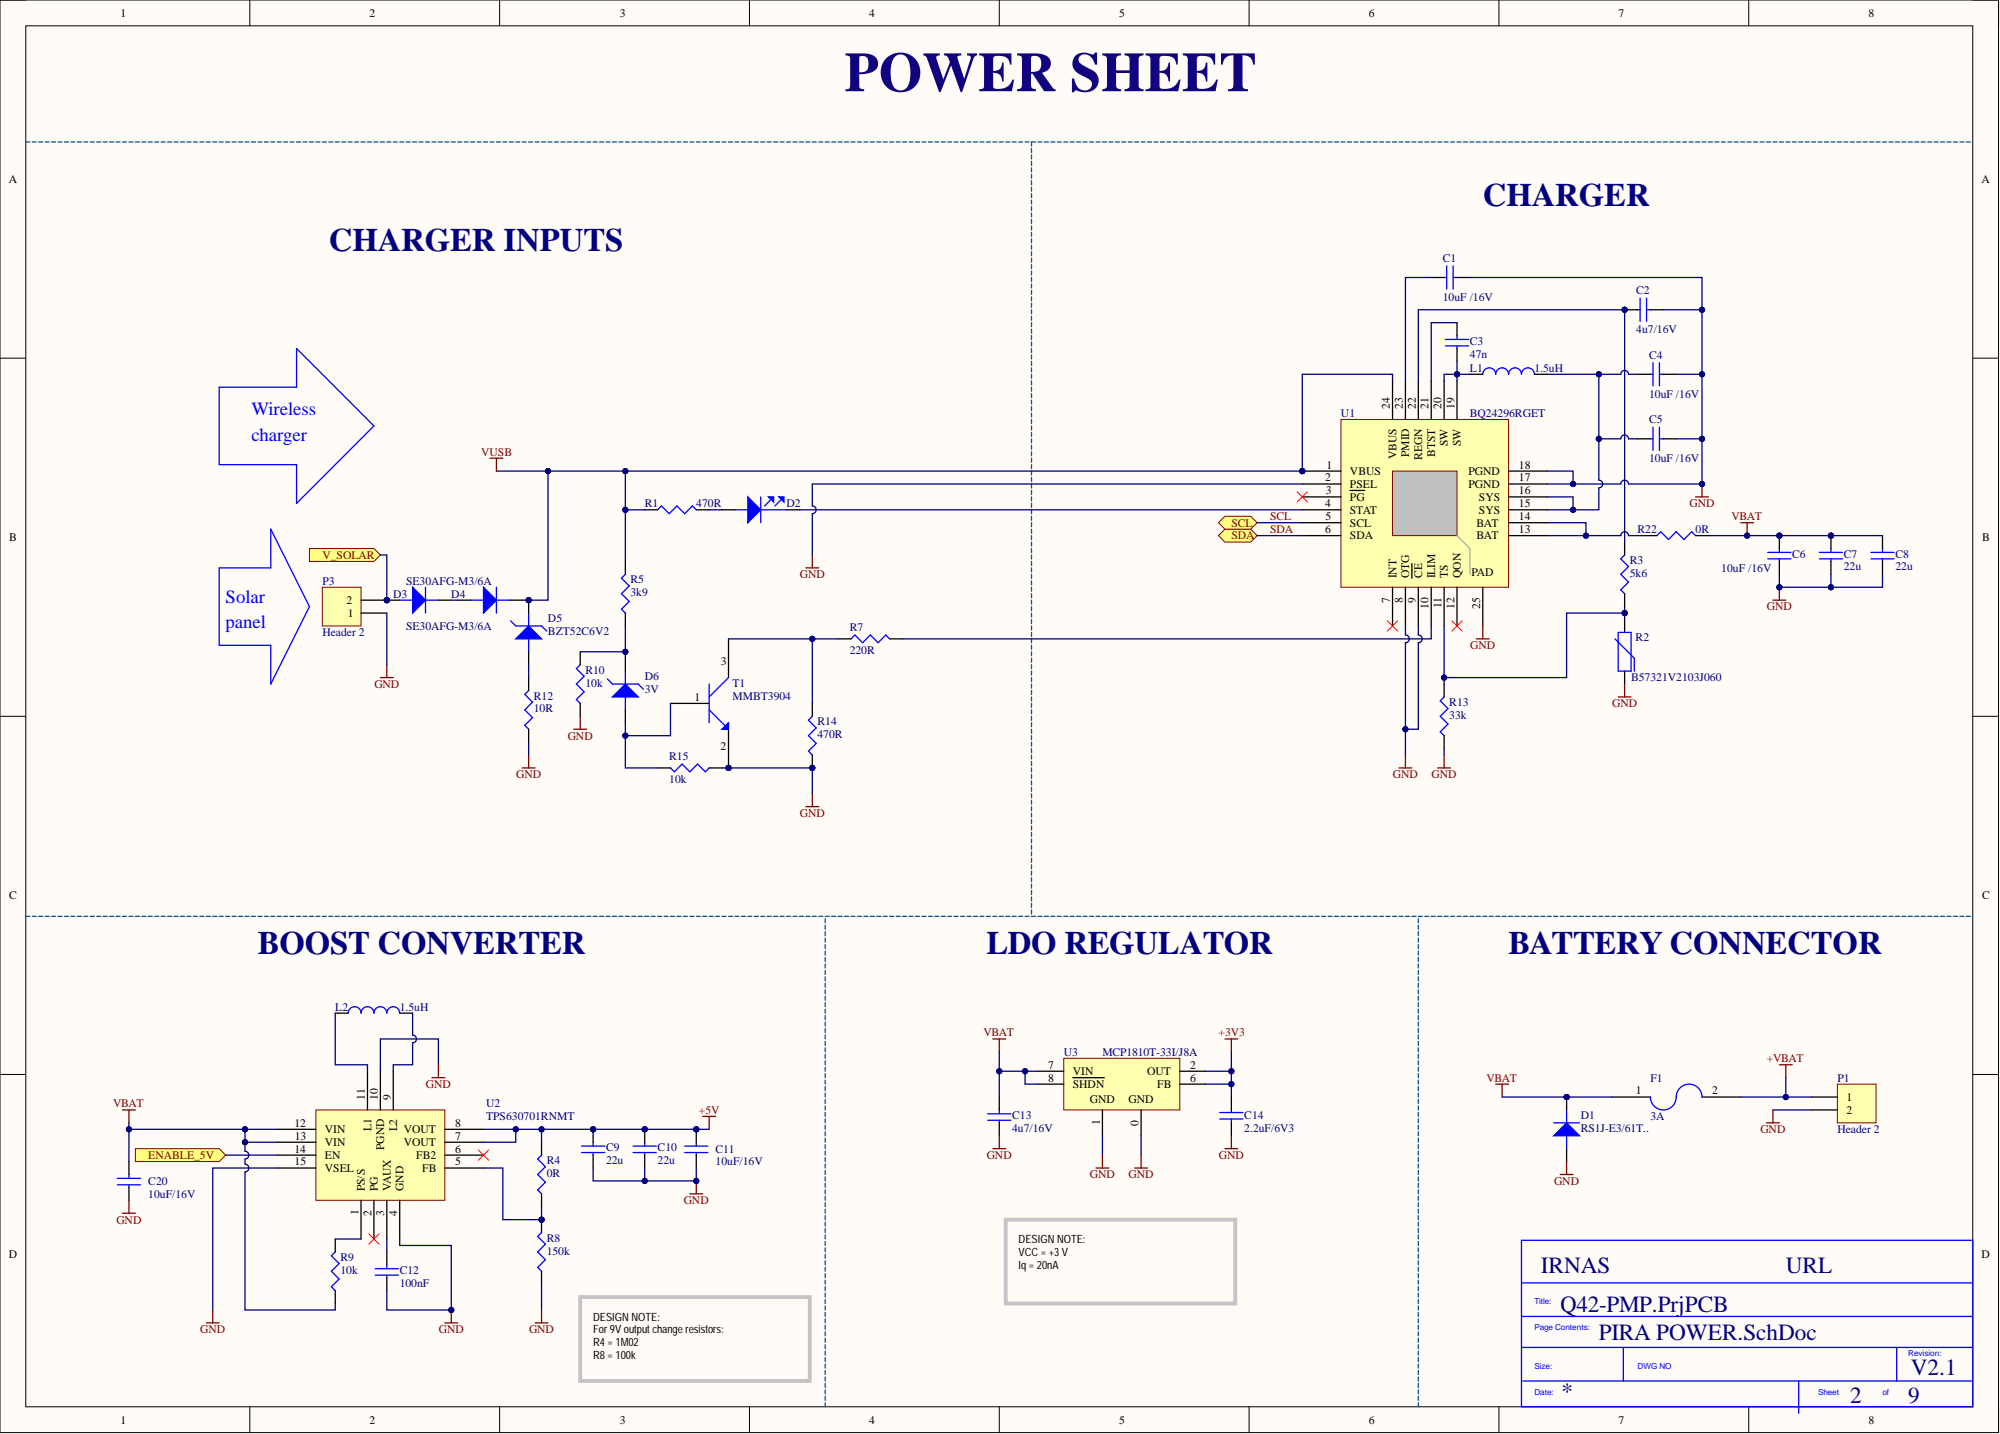
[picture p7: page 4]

SW 19 SW 20 BTST 21 REGN 22 PMID 23 VBUS 24

VBUS 1

Size: | DWG NO | Revision:

Date:

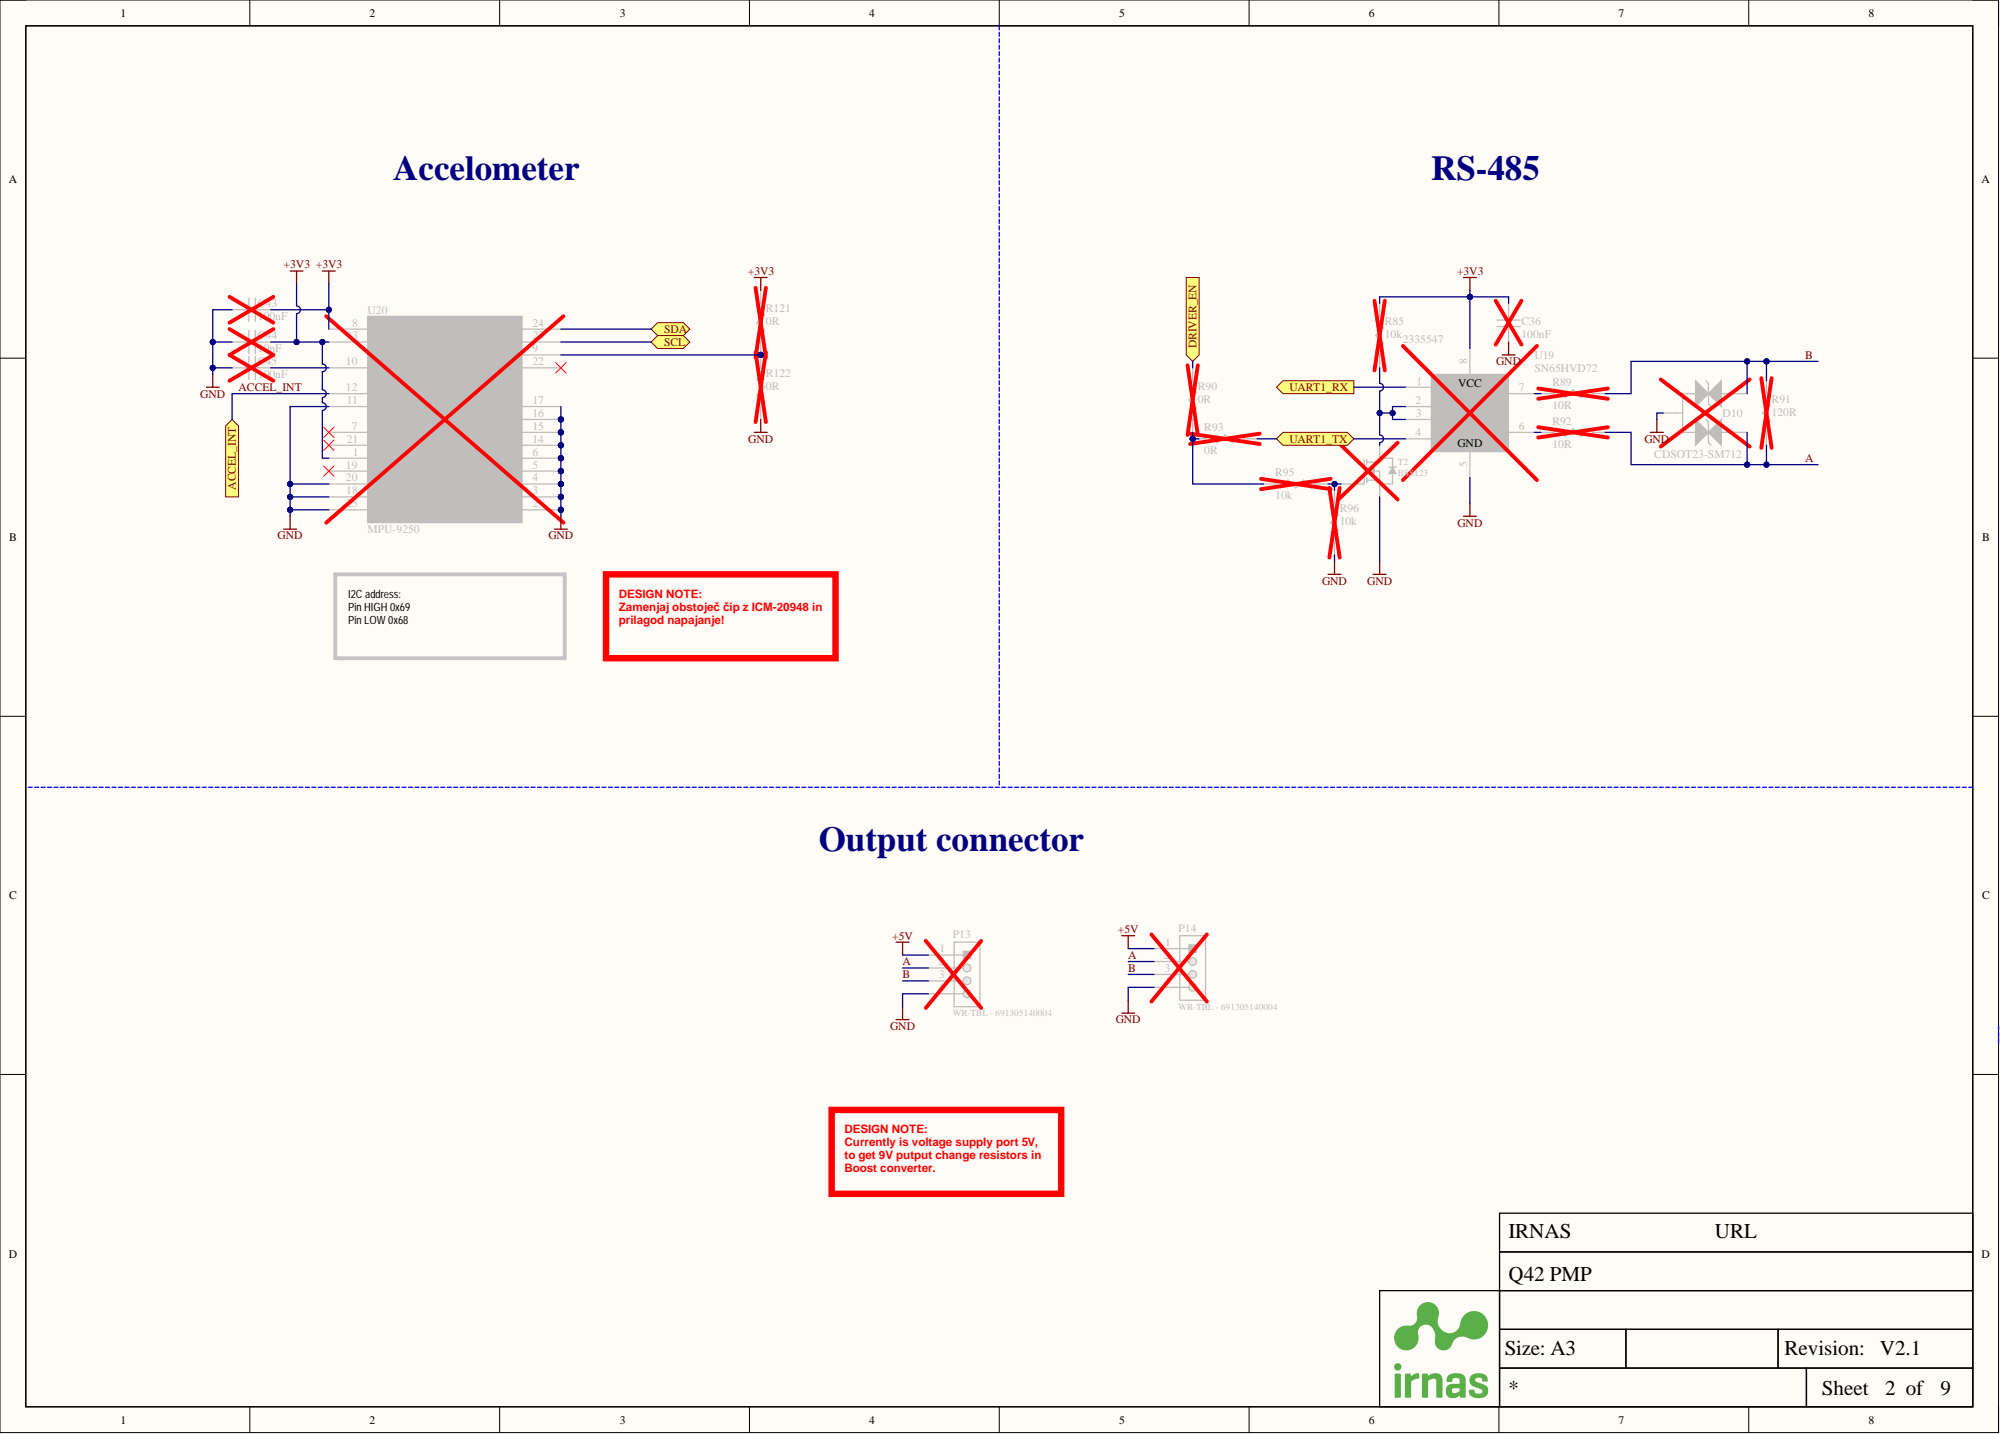
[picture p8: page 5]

DESIGN NOTE:
Zamenjaj obstoječ čip z ICM-20948 in
prilagod napajanje!

Currently is voltage supply port 5V,
to get 9V putput change resistors in
Boost converter.

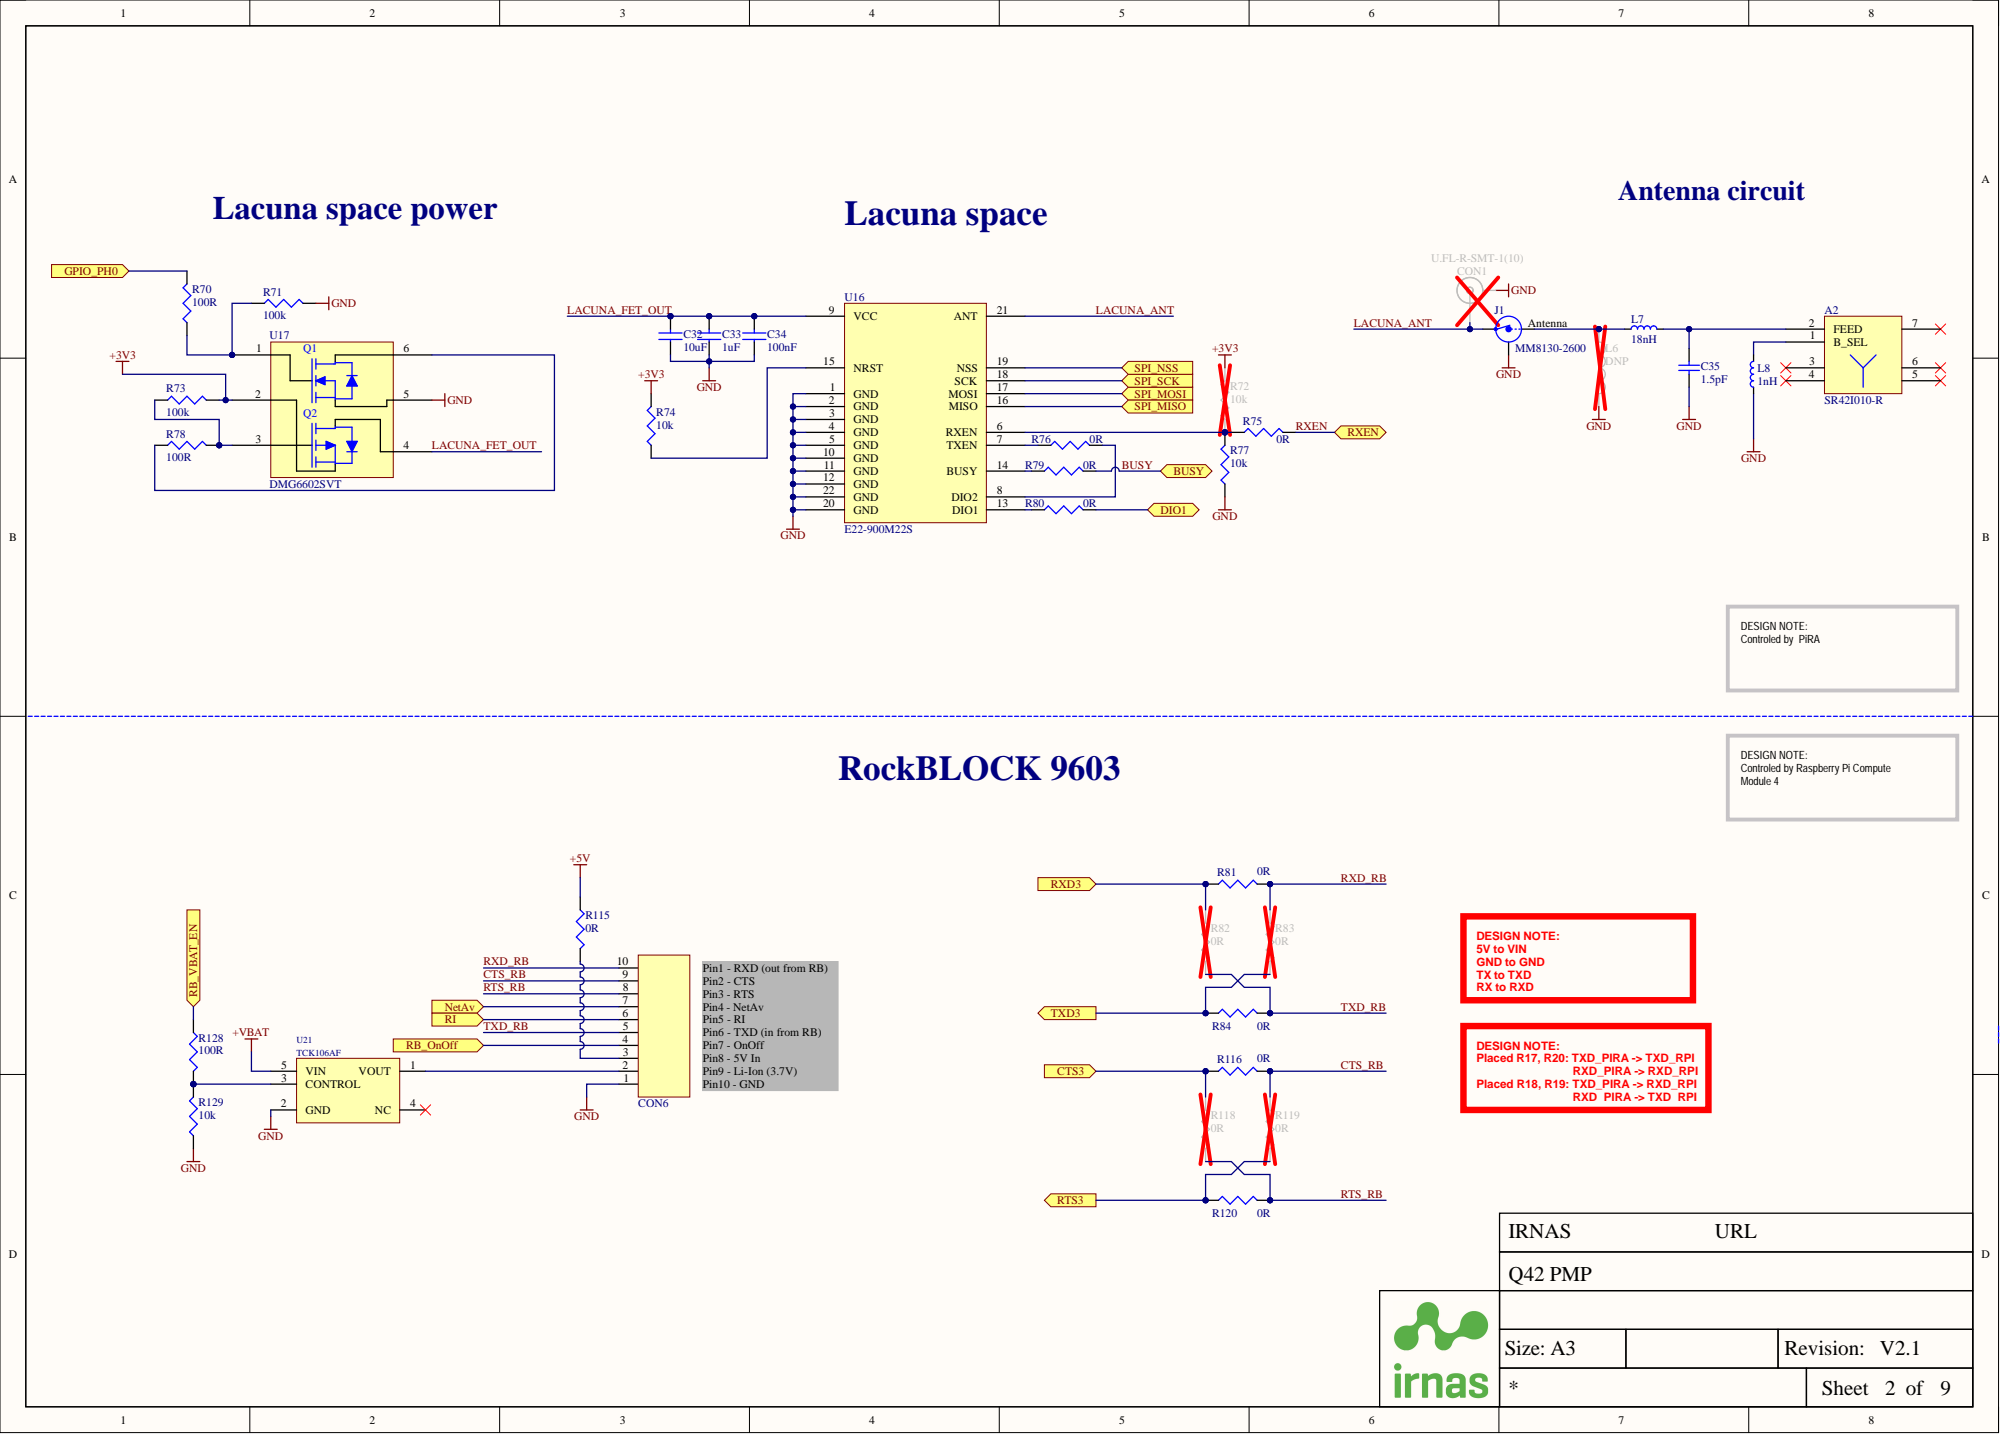
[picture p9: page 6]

GND | GND 1

GND 2
GND 3
GND 4

DESIGN NOTE:
Controled by Raspberry Pi Compute
Module 4

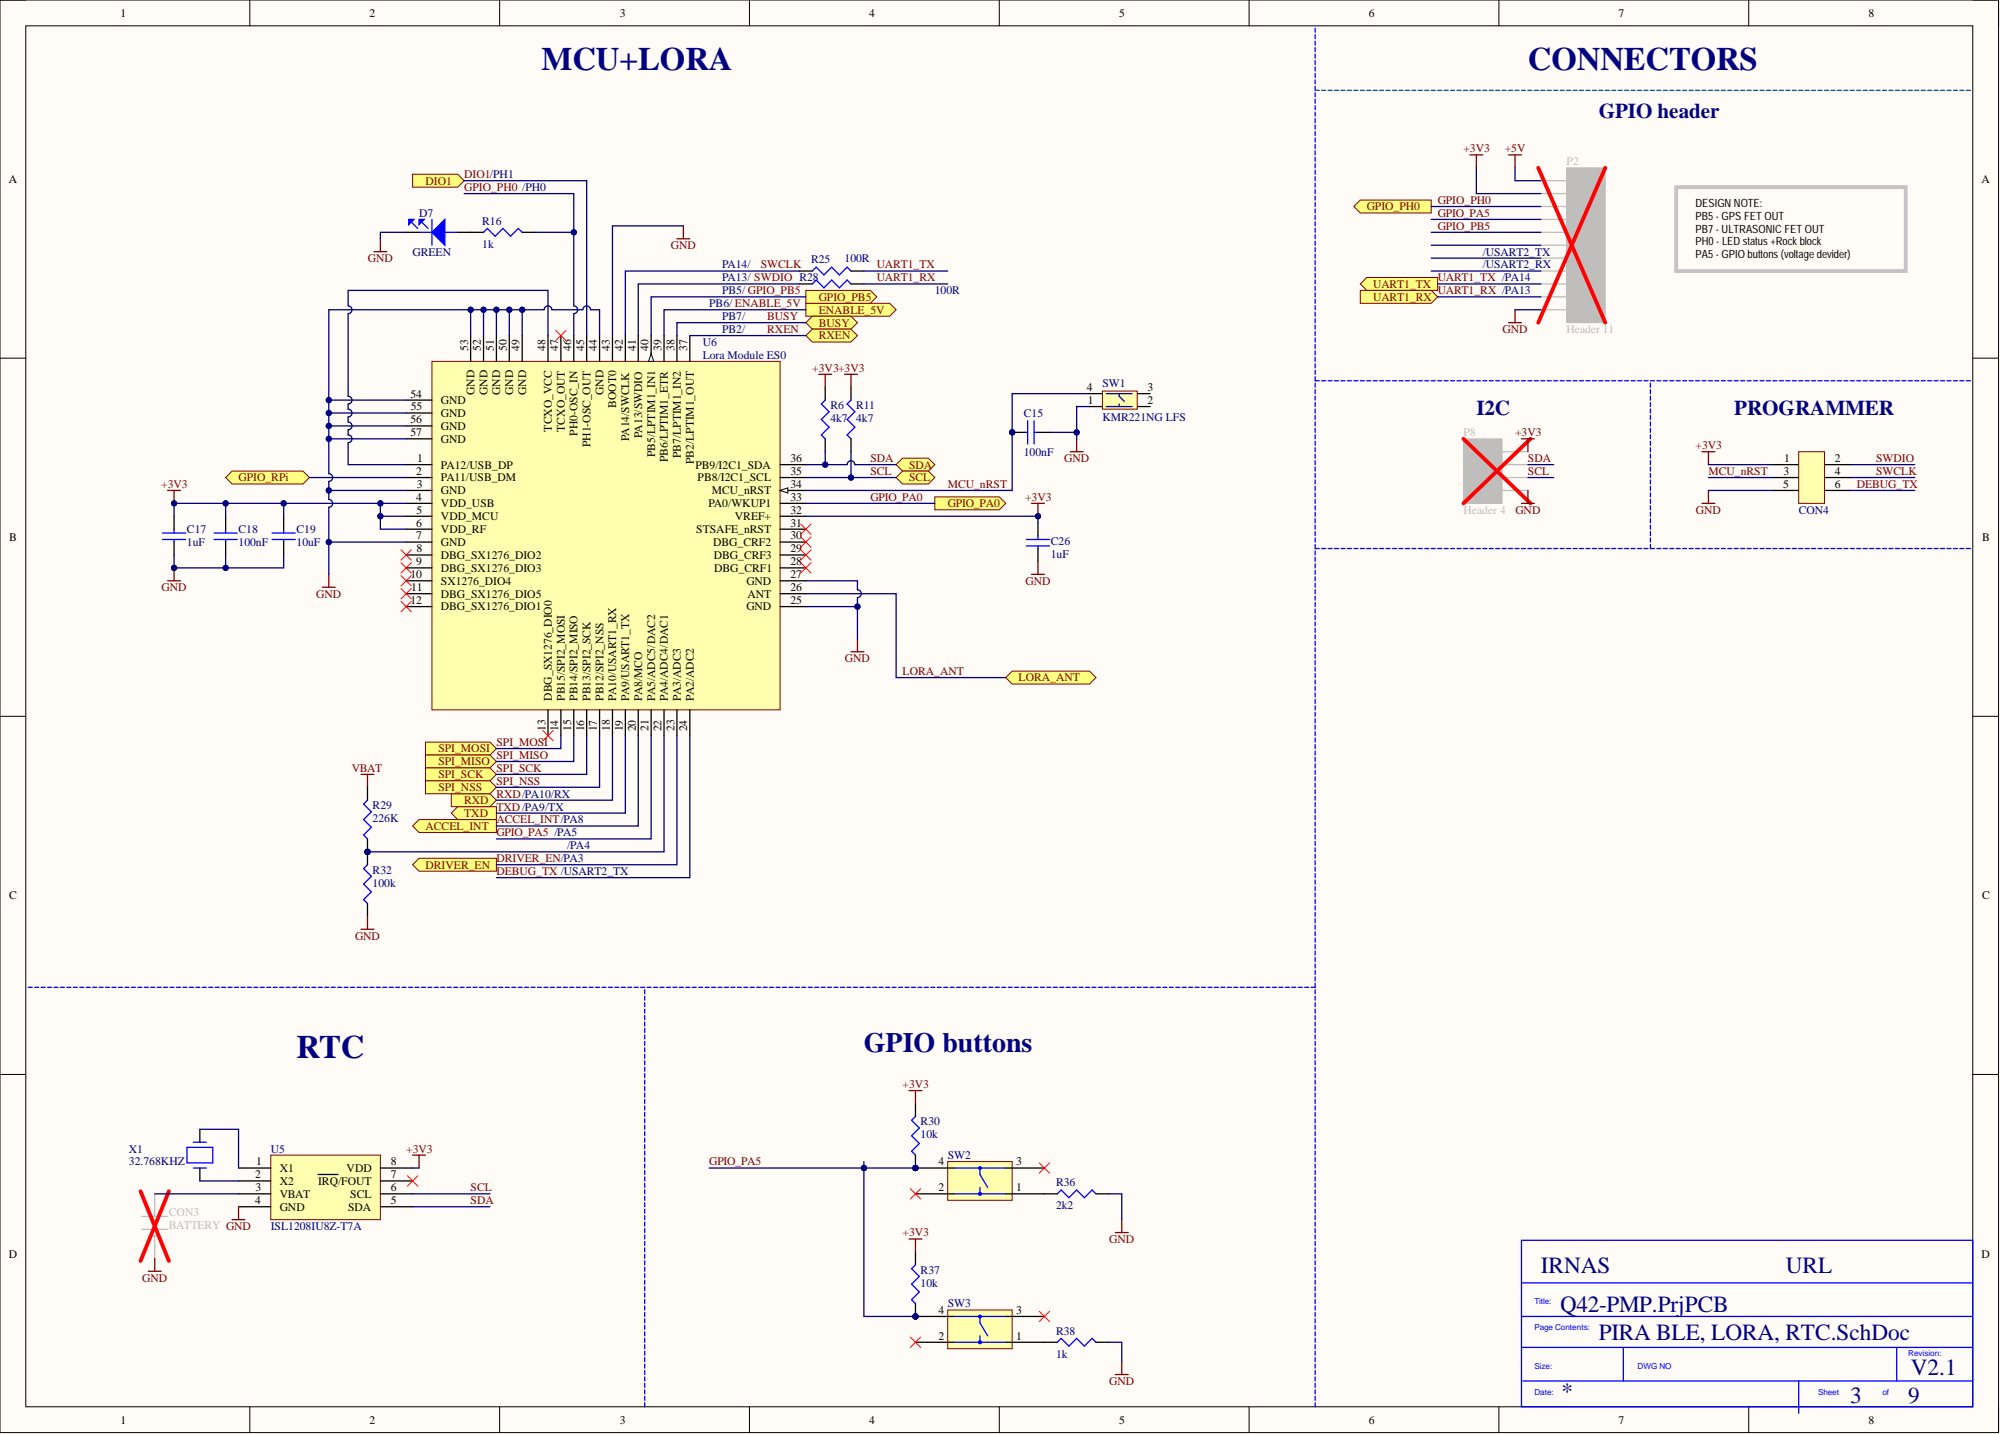
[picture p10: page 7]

DESIGN NOTE:
PB5 - GPS FET OUT
PB7 - ULTRASONIC FET OUT
PH0 - LED status +Rock block
PA5 - GPIO buttons (voltage devider)

1k GREEN

PB6/ ENABLE_5V
PB7/ BUSY

GND 50 GND 51 GND 52 GND 53

GND 55
GND 56
GND 57

MCU_nRST

VDD_USB 4

VDD_RF 6

Q42-PMP.PrjPCB
PIRA BLE, LORA, RTC.SchDoc

Size: | DWG NO | Revision:

Date:

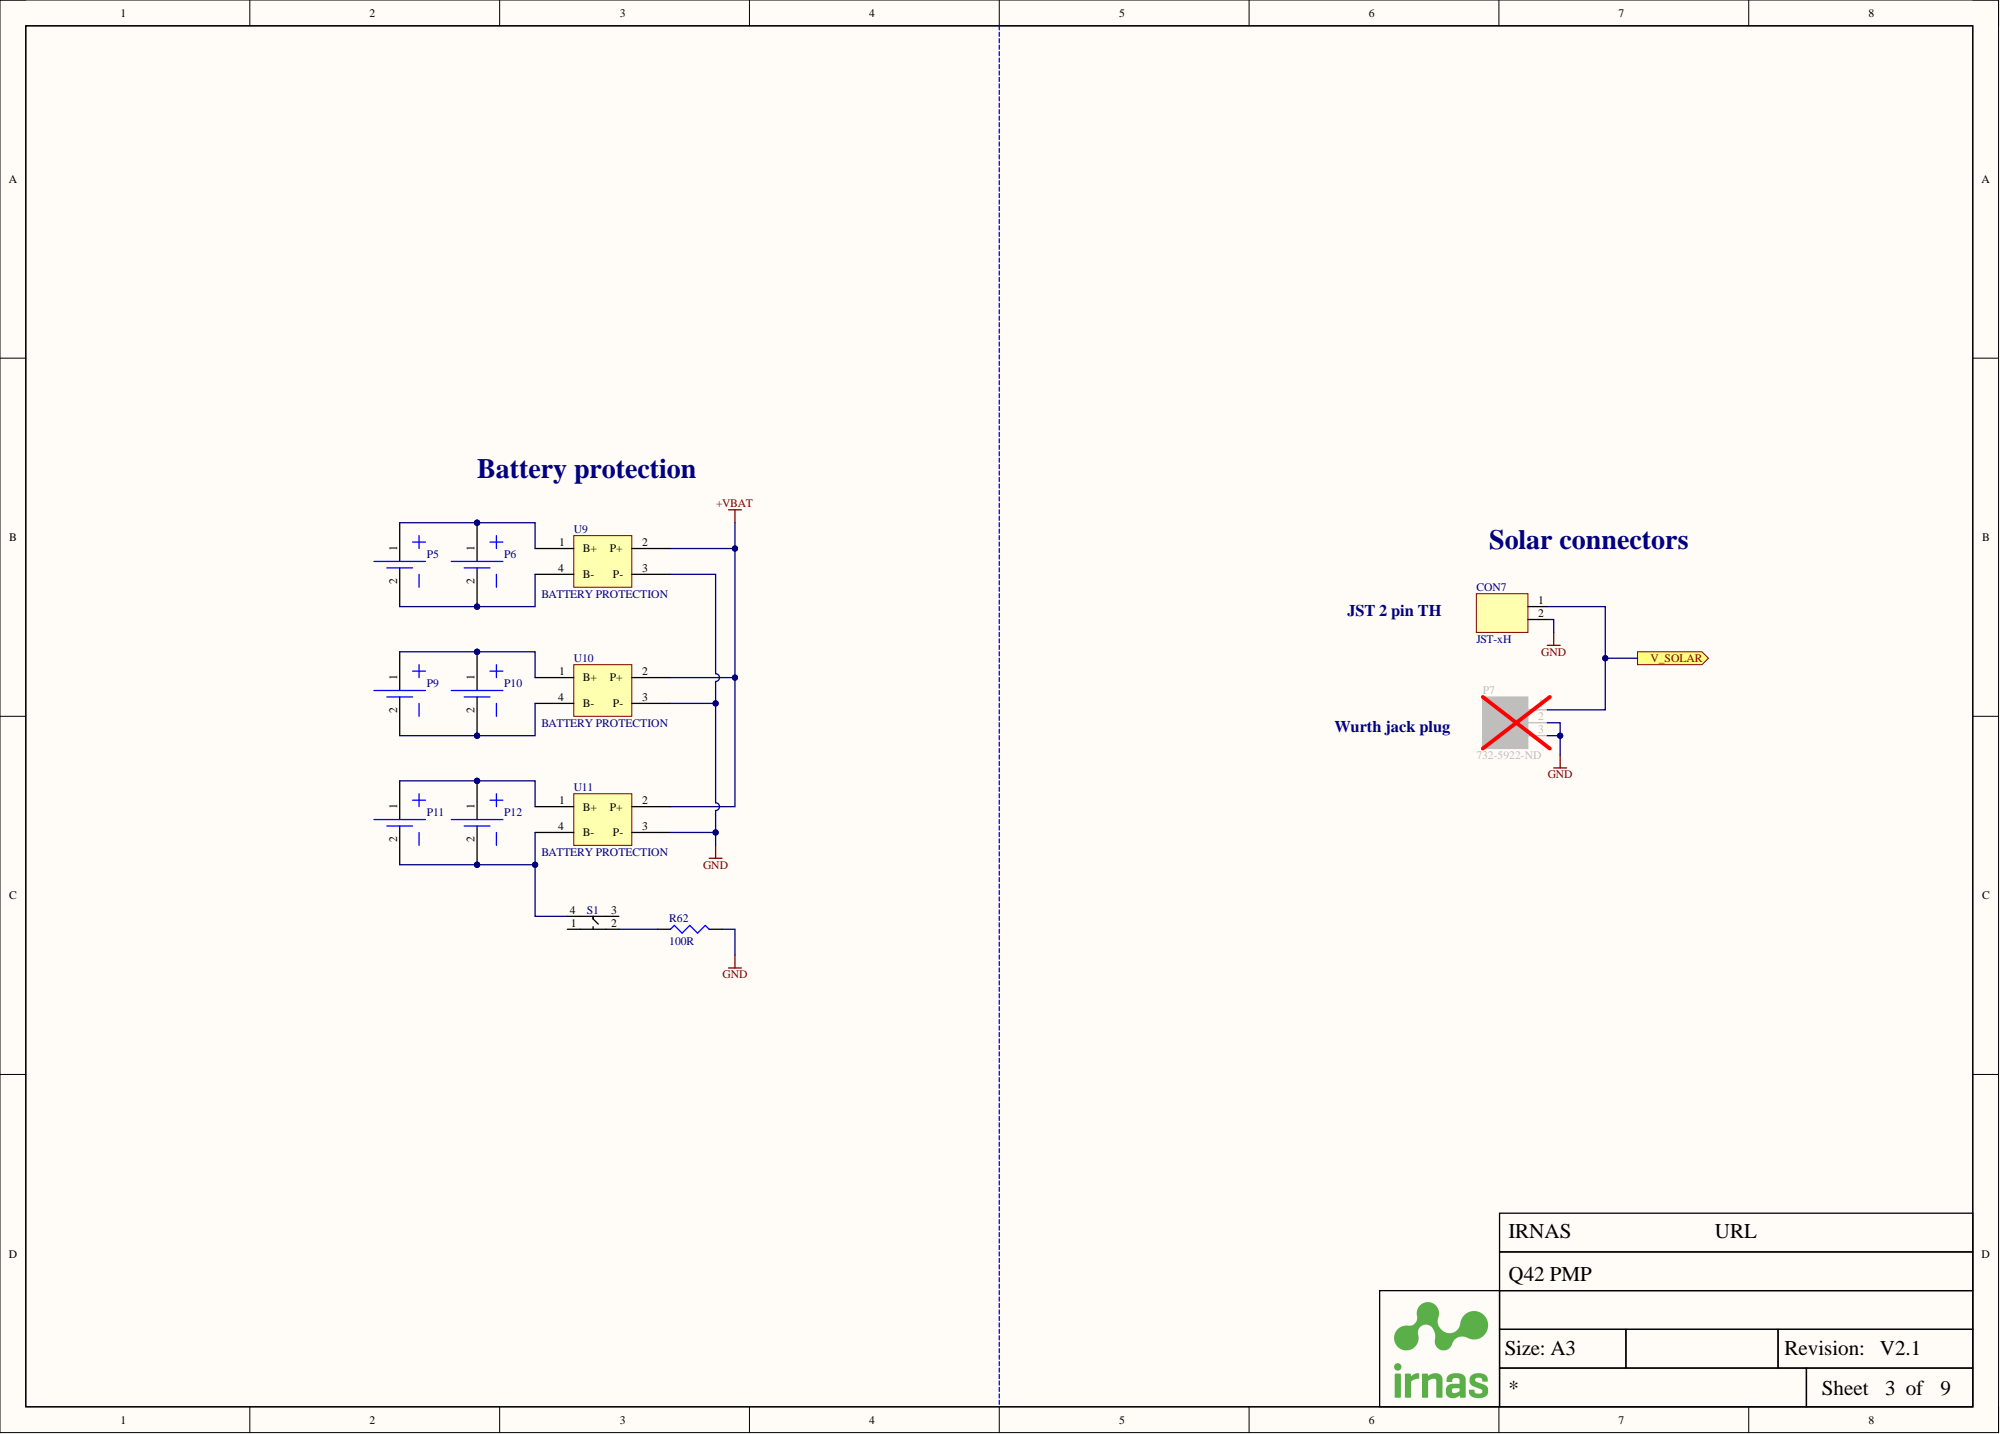
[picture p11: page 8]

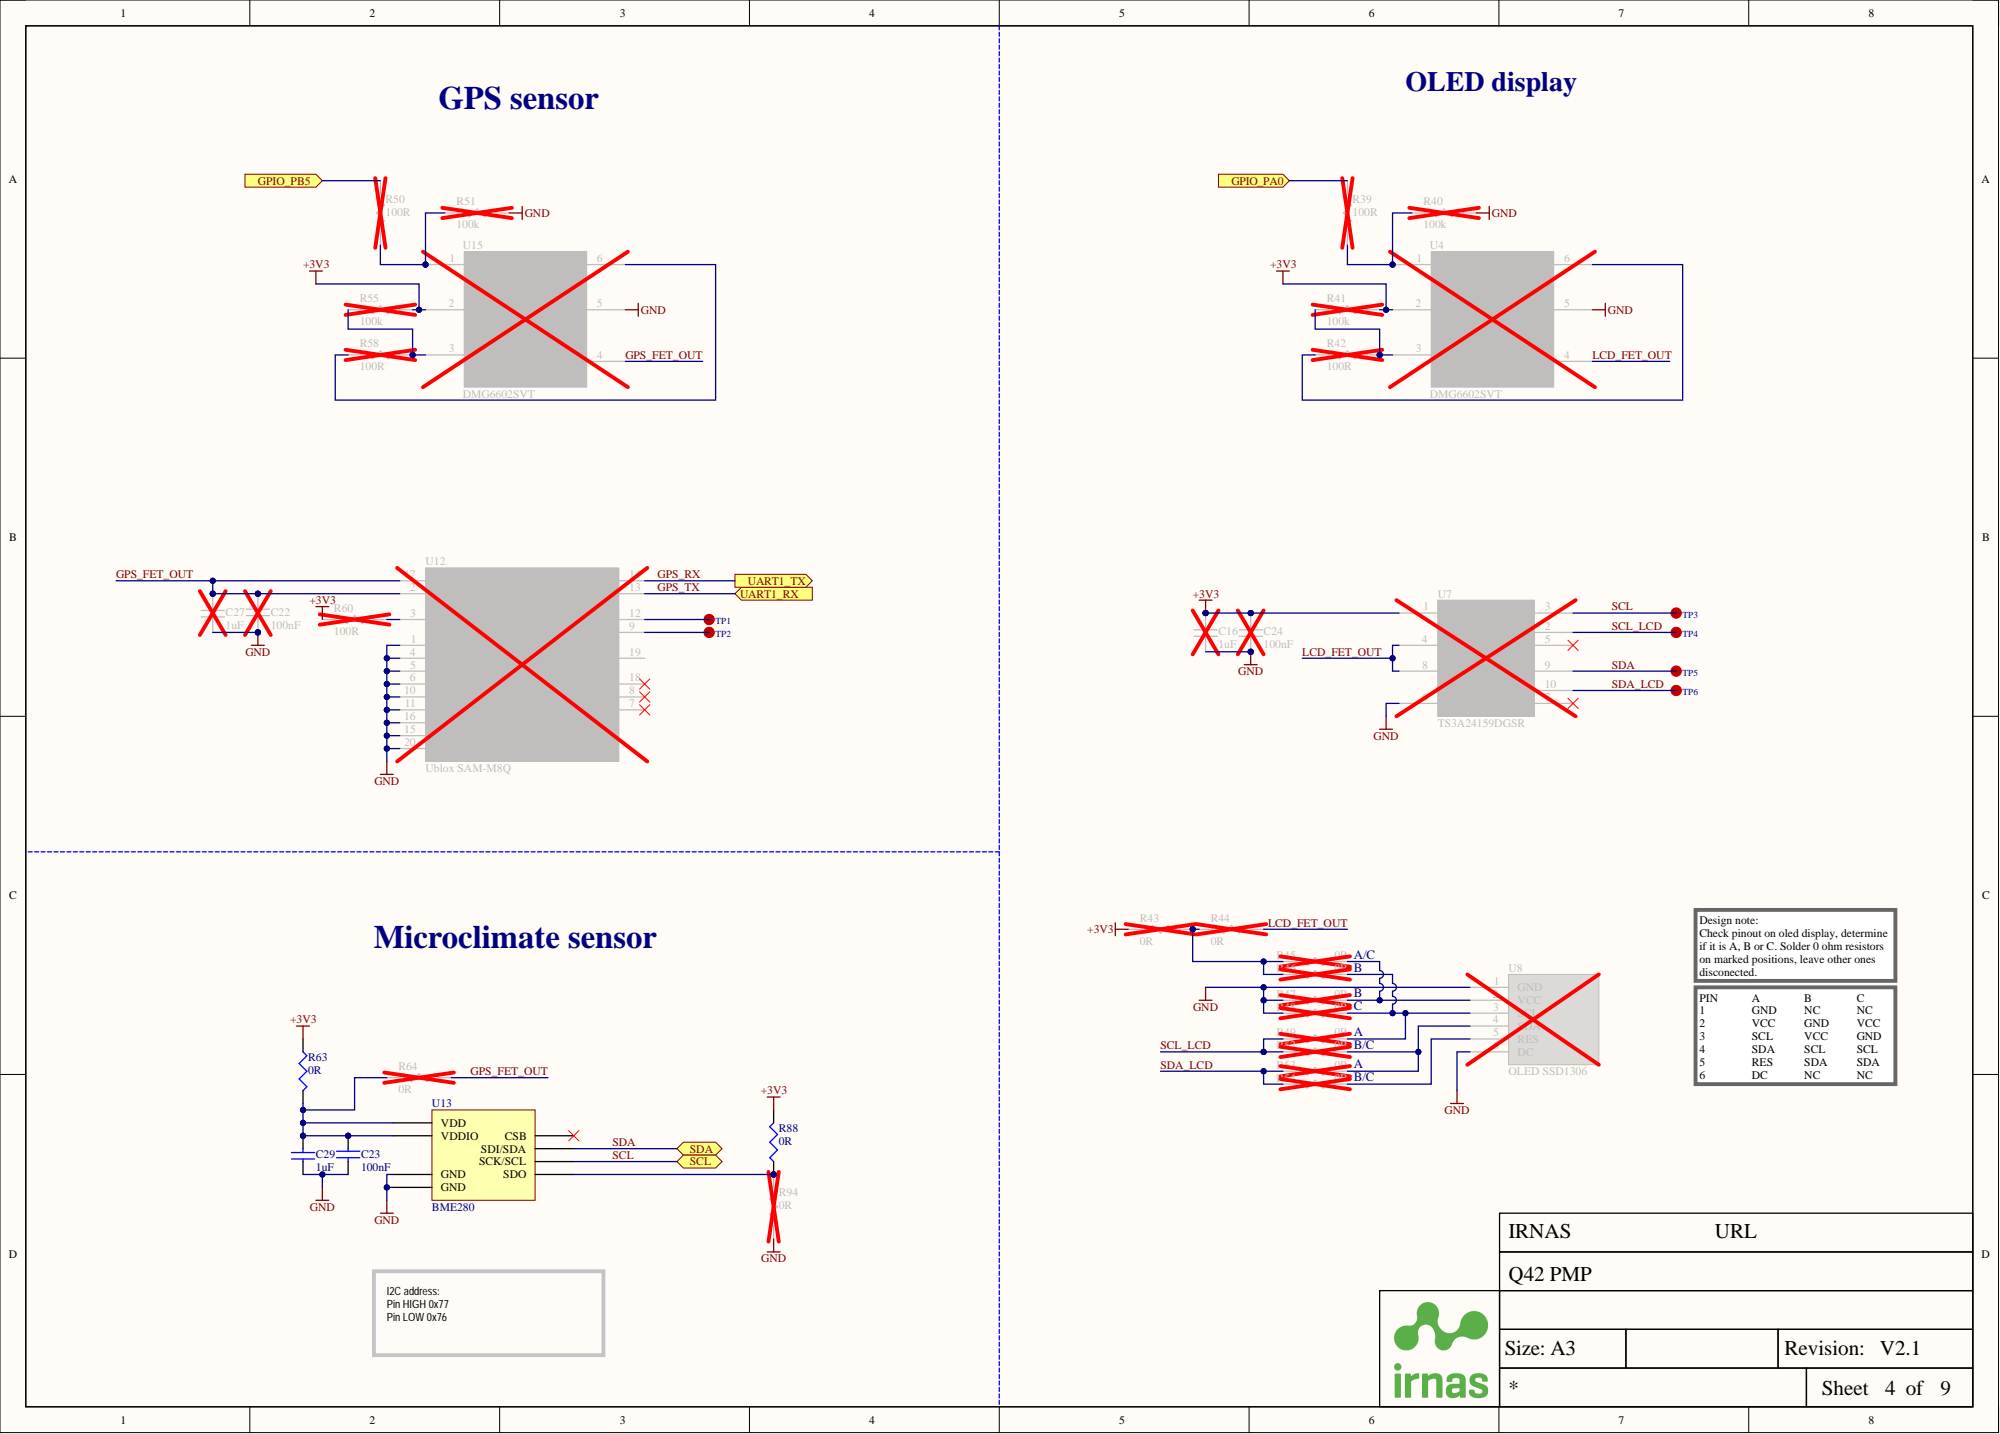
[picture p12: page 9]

GND 15 GND 16

GND 20

Design note:
Check pinout on oled display, determine
if it is A, B or C. Solder 0 ohm resistors
on marked positions, leave other ones
disconected.
